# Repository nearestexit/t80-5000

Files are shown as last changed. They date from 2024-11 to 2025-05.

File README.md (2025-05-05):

# T80-5000 & T80-5700

[QMK](https://github.com/qmk/qmk_firmware) Compatible Open Hardware USB-C PCBs for the vintage [Cherry G80-5000](https://web.archive.org/web/20250114051116/https://deskthority.net/wiki/Cherry_G80-5000) split ergonomic keyboard and its companion numpad, the G80-5700.

## Overview
The original G80-5000 has two halves which are attached together with a spring, similar to the IBM M15 and the Apple Adjustable Keyboard. They cannot be detached from each other, and the right half must always act as the host.
The original G80-5700 companion numpad can only function when plugged in to the right half of the G80-5000.

This project brings the G80-5000 & 5700 into the 21st century, with all three pieces able to function independently.
There are four PCBs included in this project: the T80-5000 Left, T80-5000 Right, T80-5000 Daughterboard, and T80-5700.
The T80-5000 Left & Right work with QMK's [split keyboard](https://docs.qmk.fm/features/split_keyboard) functionality, and the T80-5700 functions as an independent keyboard which can be passed through the right half's USB hub.

Production files are included for production at [JLCPCB](https://jlcpcb.com/).

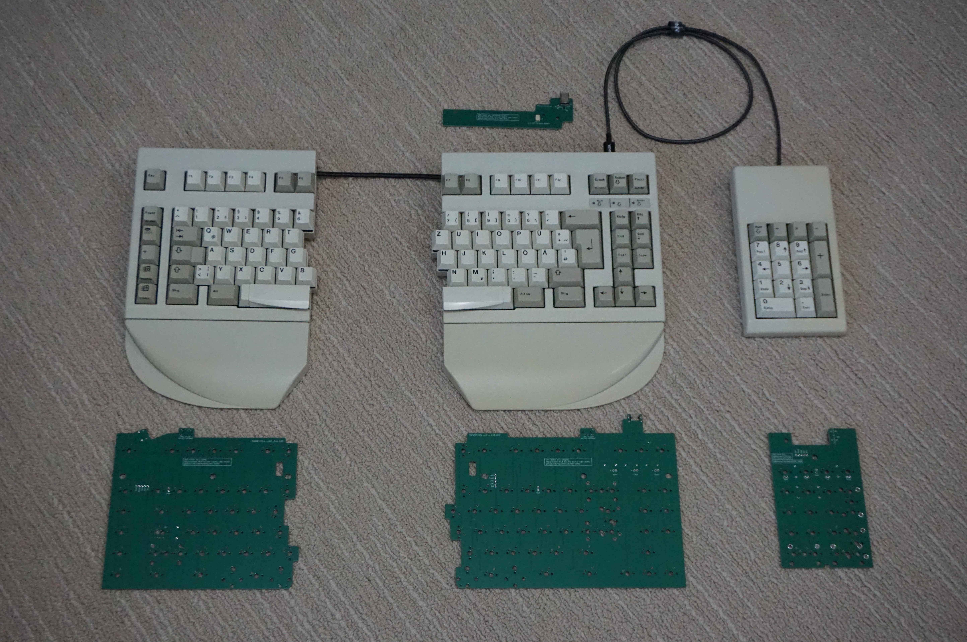
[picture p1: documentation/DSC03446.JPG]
Overview


## Features
 - USB-C in several configuration options, including internally attached and externally detachable
 - Integrated USB2.0 hub intended for T80-5700 numpad to support passthrough like the original G80-5700
 - [RP2040](https://www.raspberrypi.com/products/rp2040/specifications/) MCU(s) supported by the open-source QMK firmware project

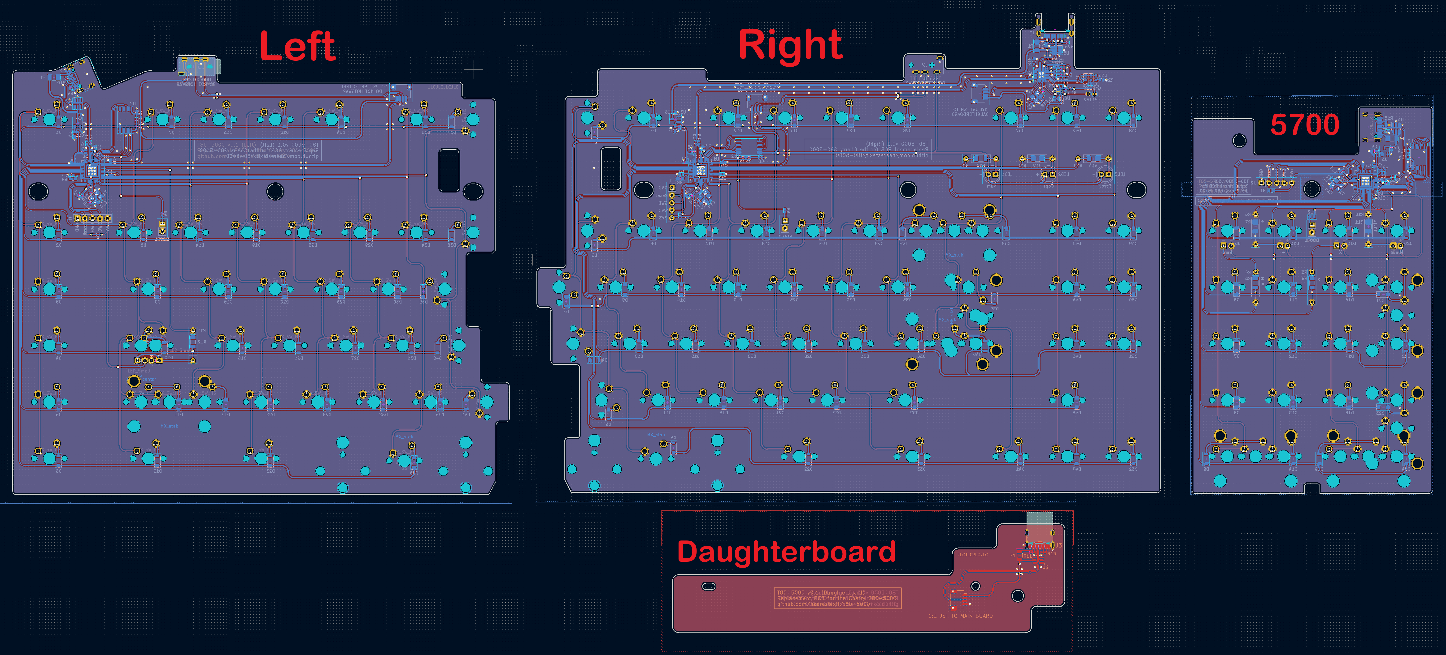
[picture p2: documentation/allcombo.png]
PCB


## Supported layouts
 - ISO and ANSI
 - Split backspace
 - 5x4 ortholinear numpad
 - Stepped and centered caps lock
   
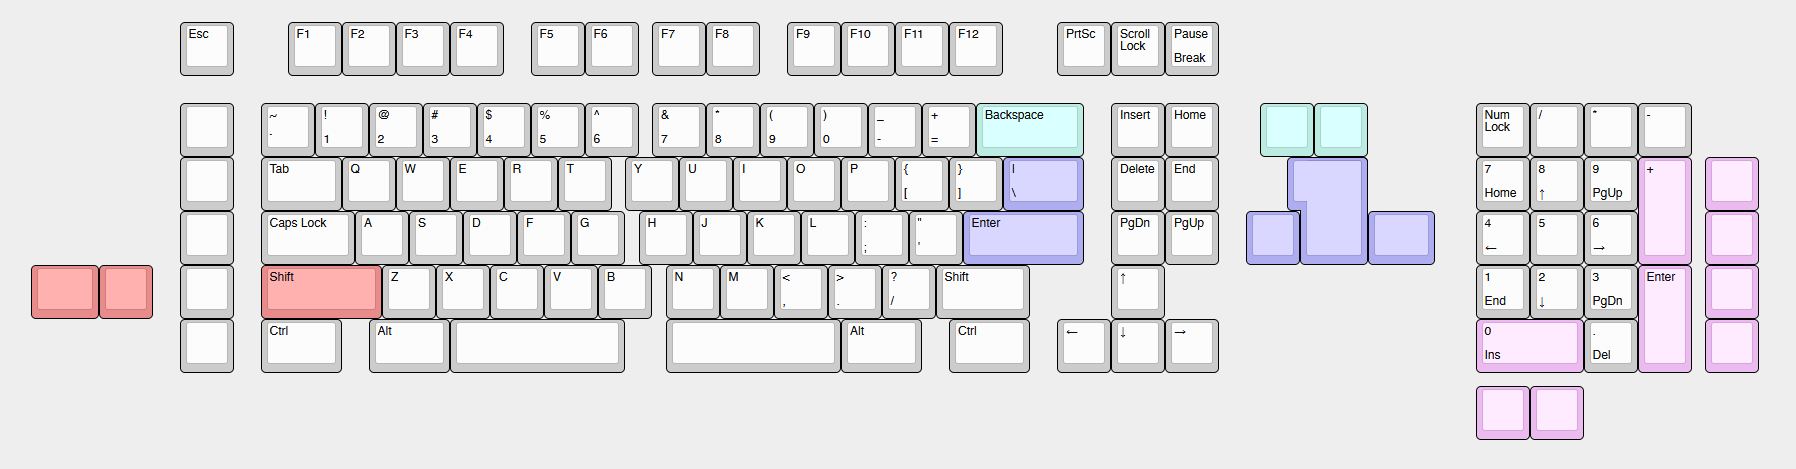
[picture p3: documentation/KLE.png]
T80-5000 and 5700 layout options


## Configuration options
 - The left and right halves can function independently or in a primary/secondary configuration.
 - The left half's USB-C connector is only accessible internally.
 - The right half's USB-C connector takes advantage of the cutout for the original 5-pin mini DIN to be externally detachable. It is recommended to use the right half as the host.
 - The left and right half can be connected by an internally attached TRRS cable or 4-pin JST-SH cable.
 - The JST-SH cable is small enough to fit through a replacement spring.
 - The daughterboard fits in the right half, leverages the same cutout in the case, and serves as the downstream facing USB-C port for the integrated USB hub. It is connected to the right half with a 4-pin JST-SH cable.
 - The T80-5700 has an internally detachable USB-C connector and functions as an independent USB device.

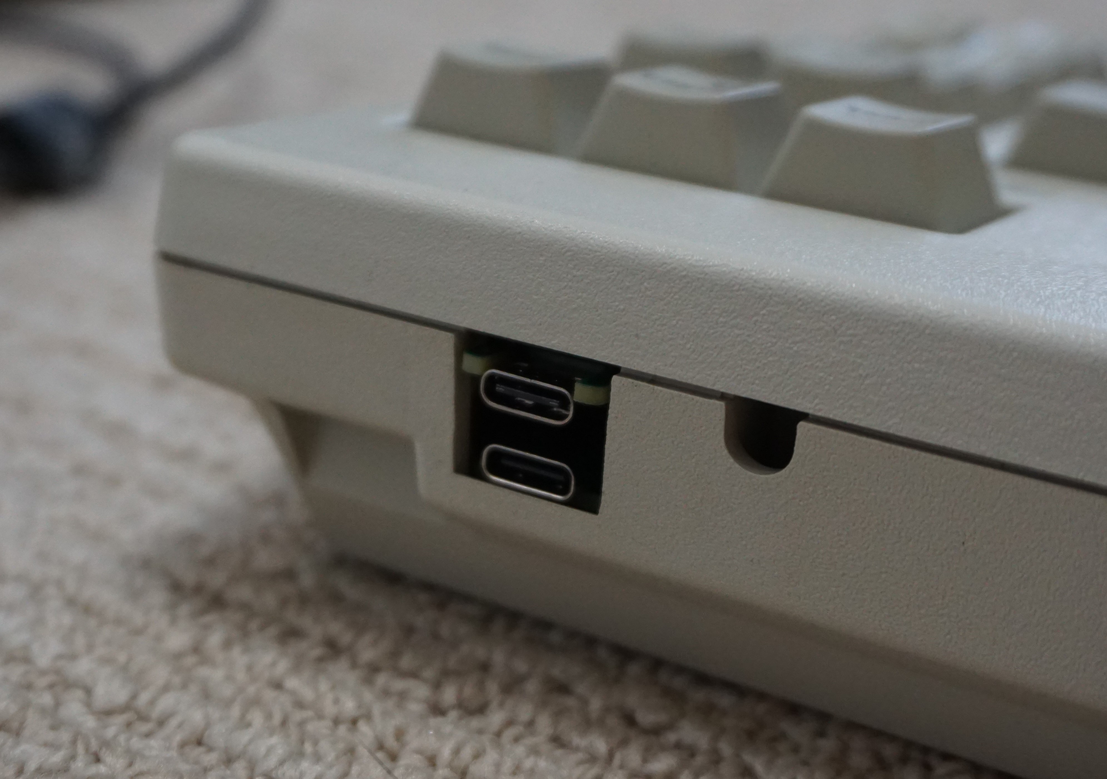
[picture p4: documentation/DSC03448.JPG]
USB port pictures

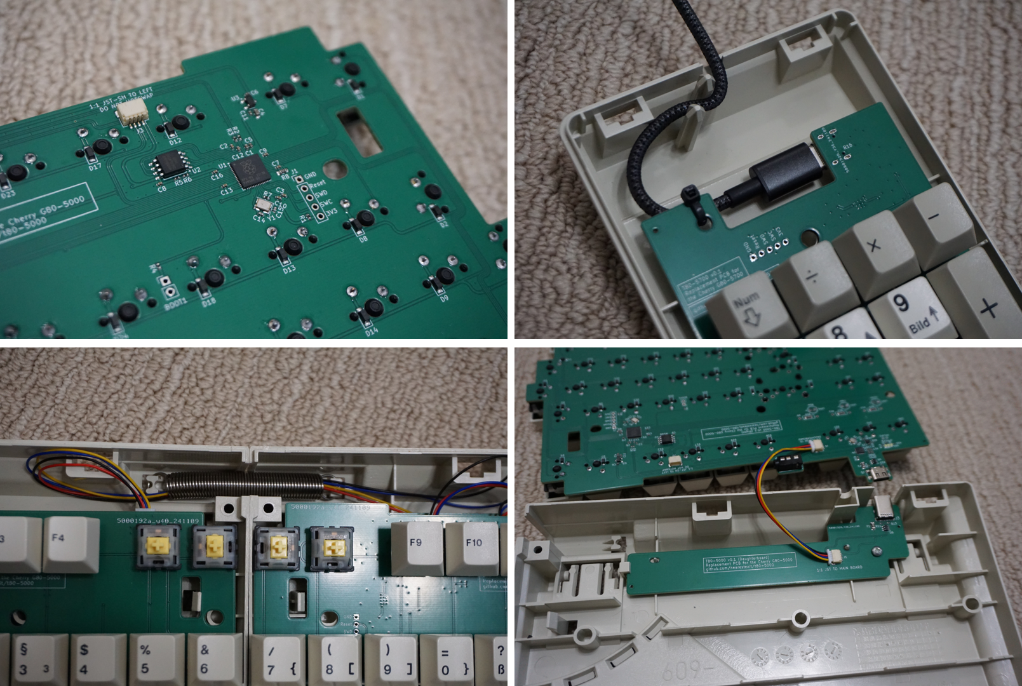
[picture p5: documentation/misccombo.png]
Combo picture


## JLCPCB Ordering Information
1. On jlcpcb.com, click "order now" and "add gerber file"
2. Navigate to the directory with the gerber.zip - for example, t80-5000-left\jlcpcb\production_files
3. Wait for the gerber to upload.
4. Select the number of PCBs you wish to build.
5. Make sure PCB thickness is set to 1.6mm.
6. Make sure Via covering is set to "tented".
7. Make sure Min via hole size/diameter is set to "0.3mm"
8. For "Mark on PCB" select "Order Number (Specify Position)"
9. Turn the "PCB Assembly" option on
10. Make sure PCBA type is set to "Economic"
11. For "Assembly side", if you are ordering the daughterboard select "top side", otherwise select "bottom side"
12. Click "next", and then "next" again
13. Click "Add BOM File" and select the BOM csv - for example, BOM-T80-5000-left.csv
14. Click "Add CPL File" and select the CPL csv - for example, CPL-T80-5000-left.csv
15. Click "Process BOM and CPL"
16. Make sure all parts are in stock - if any are not in stock, you will need to find replacements
17. If you wish to purchase and solder the TRRS sockets separately (recommended to save money), unselect "J2" in this list
18. **IMPORTANT:** Click "Bottom" to view the bottom side of the PCB, and begin inspecting the component placements. You **WILL** need to correct some component rotations. If you are not sure at this step, do not continue!
19. Click "next" and finish checking out.

When I ordered the V0.1 prototype on 11/8/2024, The total price was $207.63 total for Qty. 5 of all PCBs (left, right, daughterboard, and 5700) plus shipping, or roughly $52.71 per set of Left, Right, Daughterboard, and 5700.

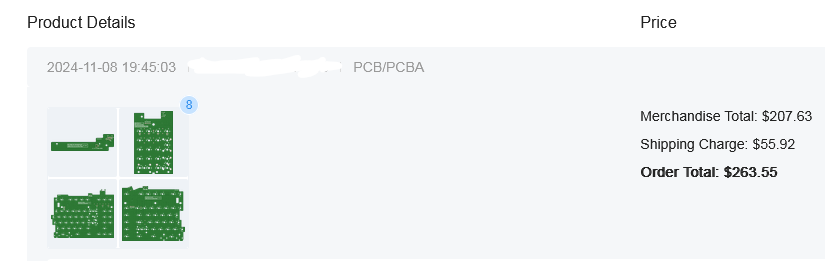
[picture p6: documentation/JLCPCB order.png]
JLCPCB order


## Additional Components:
- 1x 1:1 ~50mm 4-pin JST-SH cable to connect Left PCB to daughterboard
  - **IMPORTANT:** this must be a 1:1 cable, or else you will short VCC to ground!
  - This means that pin 1 of one connector must be wired to pin 1 of the other connector. If you are unsure, lay the cable flat with no wires crossing - if the connectors on either side are the same way up, it is NOT a 1:1 cable. If they are flipped, it is a 1:1 cable.
  - You can get 1:1 JST-SH cables from many places, but I recommend purchasing a Sparkfun QWIIC starter kit like [this](https://www.amazon.com/dp/B08HQ1VSVL)
- 1x 1:1 ~300mm 4-pin JST-SH cable **OR** TRRS cable to connect Left PCB to Right PCB
  - **IMPORTANT:** do not hotswap these connectors! Plugging or unplugging the TRRS connector with power on will short VCC to ground and potentially damage the MCU.
- 3x LEDs for lock lights
  - The board comes with 300 ohm 1206 package resistors pre-soldered. There are holes to add through-hole resistors if you want to change the resistance.
- ~113 MX-compatible switches (this will vary depending on the layout you choose - my ISO configuration uses 108 switches)
- [PJ-320A](https://www.lcsc.com/product-detail/Audio-Connectors_XKB-Connectivity-PJ-320A_C2884926.html) 3.5mm 4 pin TRRS receptacle (optional) - if you wish to use a TRRS cable and choose not to have it soldered by JLCPCB
- Spring (optional) - An image displaying the approximate measurements of the original spring is included in the documentation folder. I used [these](https://www.amazon.com/dp/B0BRHF1DBL) springs.

## Firmware
- [Vial-QMK](https://get.vial.today/) .uf2 files are provided in the firmware folder.
- To put the keyboard into bootloader mode to flash the firmware:
1. Unplug the USB cable
2. Short the BOOT pins with a pair of tweezers
3. Plug the USB cable in
4. Stop shorting the BOOT pins.
- The RP2040 will then be loaded onto your computer as a USB storage device. Drag in the .uf2 firmware file, and it will reboot.
- The boot pins can be found on the Left side by removing the 1 key, the Right side by removing the 0 key, and the Numpad by removing the * key.
- Once you have flashed the firmware, you can change the keymap from [vial.rocks](https://vial.rocks)

## Other Important Notes
- The components are soldered on to the bottom of this PCB. If you are not careful when putting the keyboard together, you can knock components off the PCB.
- The USB-C receptacles for the right half and the downstream-facing USB hub are close enough together that if the downstream USB-C port is used, cables with thick ends will not work.
- If you do not use the downstream-facing USB-C port, there is no limit to the size of the USB-C cable.
- The USB-Hub will not function if the left side is used as the host.

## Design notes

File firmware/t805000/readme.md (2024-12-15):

# nearestexit/t805000

nearestexit/t805000

*A short description of the keyboard/project*

* Keyboard Maintainer: [nearestexit](https://github.com/nearestexit)
* Hardware Supported: *The PCBs, controllers supported*
* Hardware Availability: *Links to where you can find this hardware*

Make example for this keyboard (after setting up your build environment):

    make nearestexit/t805000:default

Flashing example for this keyboard:

    make nearestexit/t805000:default:flash

See the [build environment setup](https://docs.qmk.fm/#/getting_started_build_tools) and the [make instructions](https://docs.qmk.fm/#/getting_started_make_guide) for more information. Brand new to QMK? Start with our [Complete Newbs Guide](https://docs.qmk.fm/#/newbs).

## Bootloader

Enter the bootloader in 3 ways:

* **Bootmagic reset**: Hold down the key at (0,0) in the matrix (usually the top left key or Escape) and plug in the keyboard
* **Physical reset button**: Briefly press the button on the back of the PCB - some may have pads you must short instead
* **Keycode in layout**: Press the key mapped to `QK_BOOT` if it is available

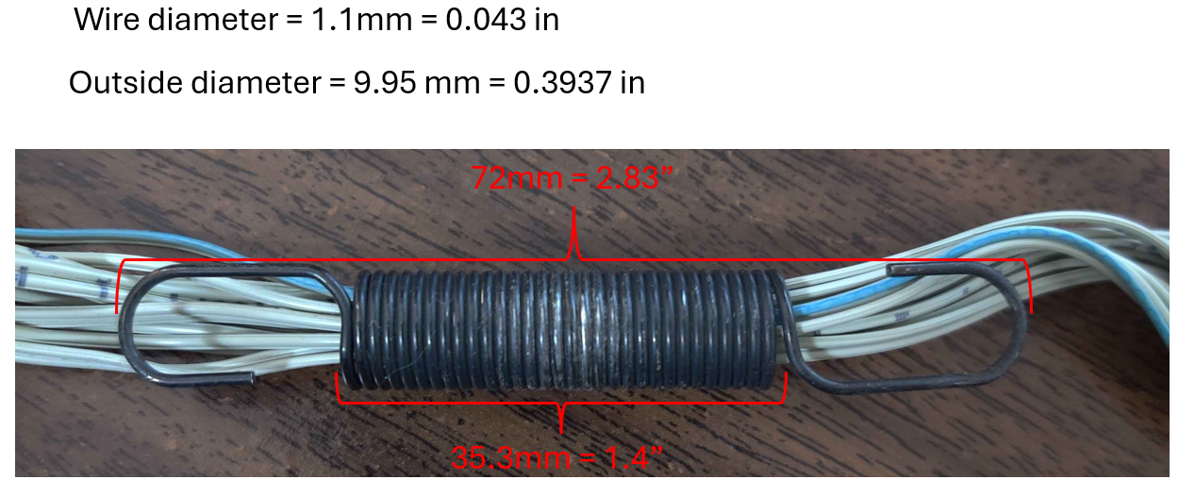
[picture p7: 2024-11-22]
documentation/spring.png

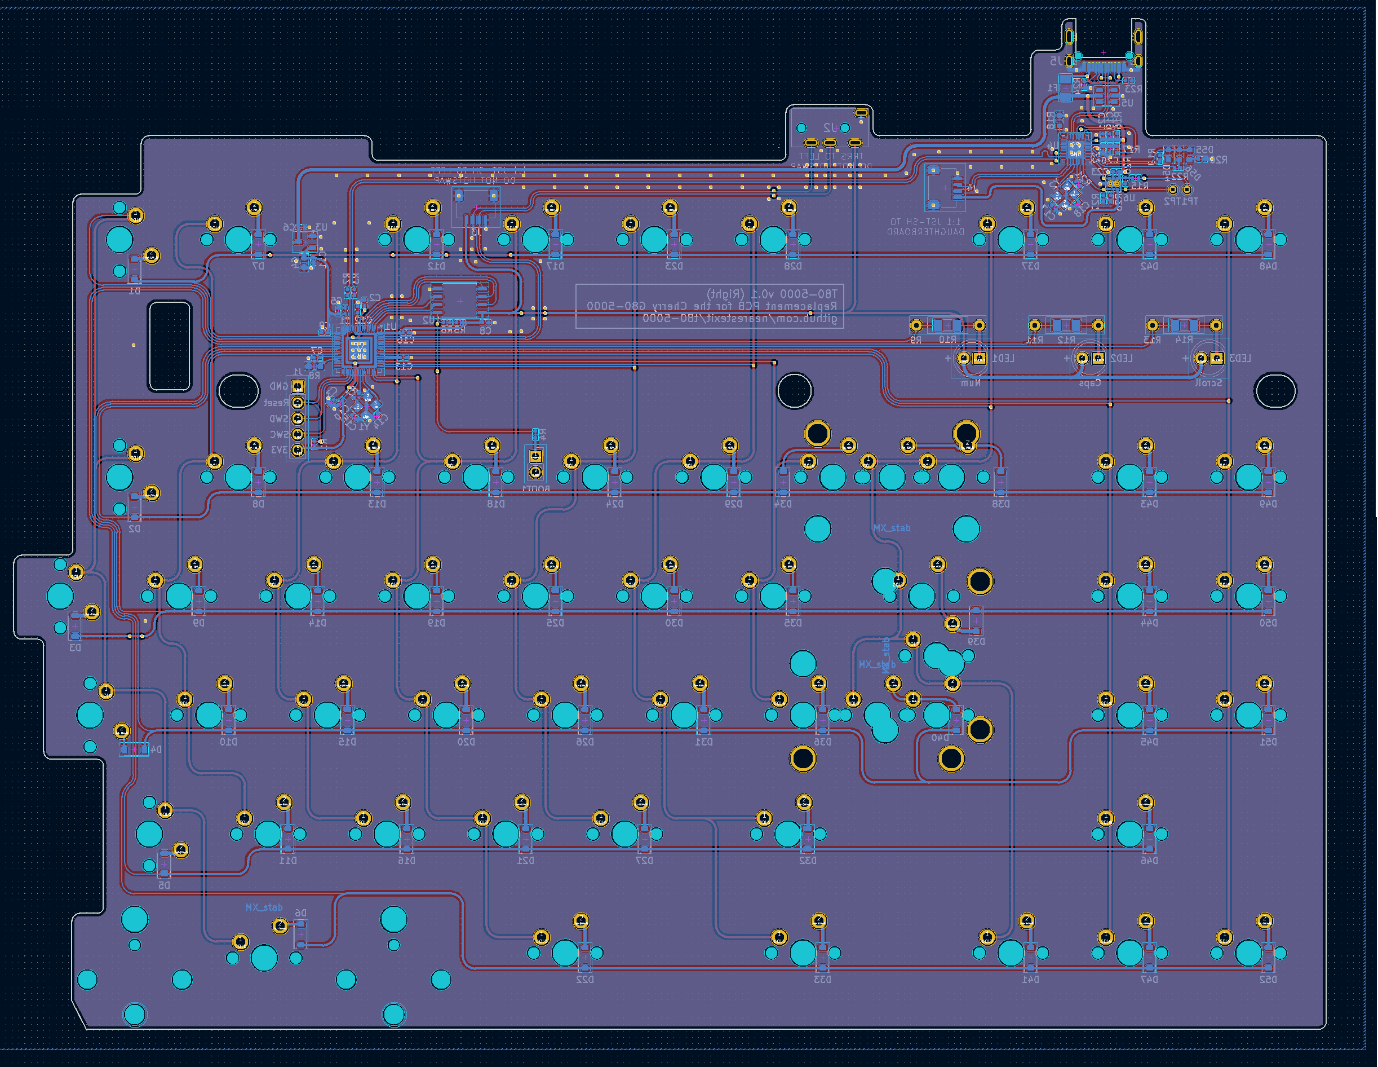
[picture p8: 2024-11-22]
documentation/right.png

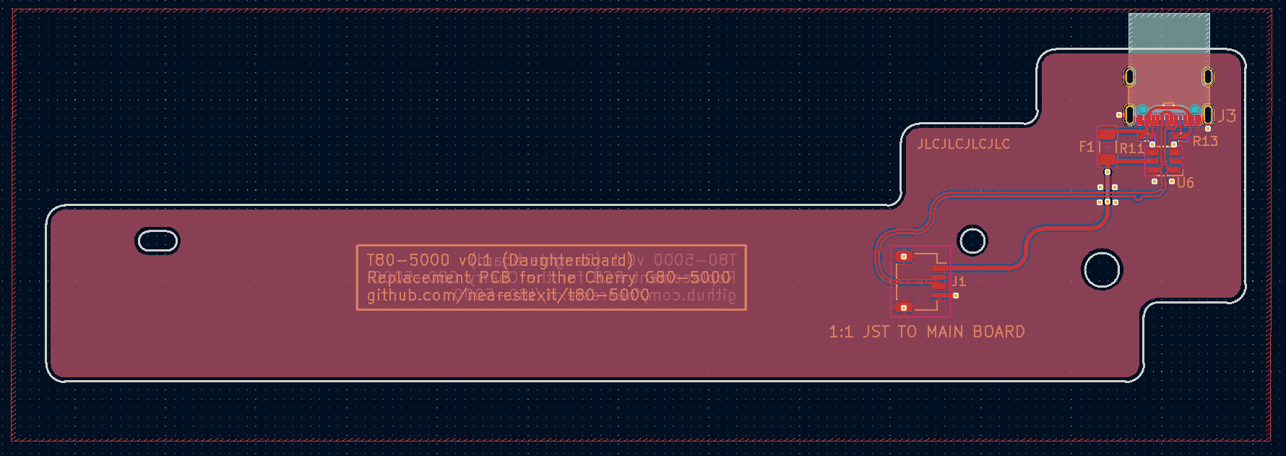
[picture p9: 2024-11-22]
documentation/daughterboard.png

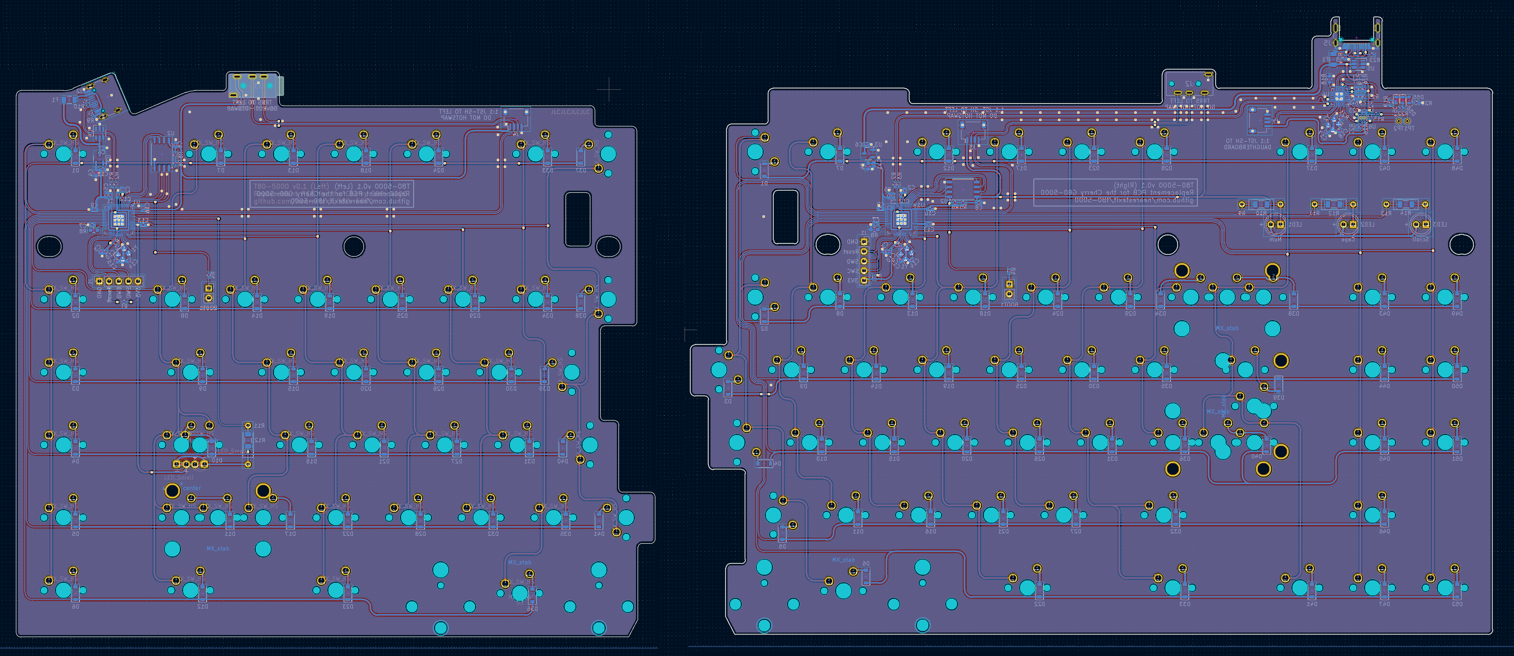
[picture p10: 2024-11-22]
documentation/leftrightcombo.png

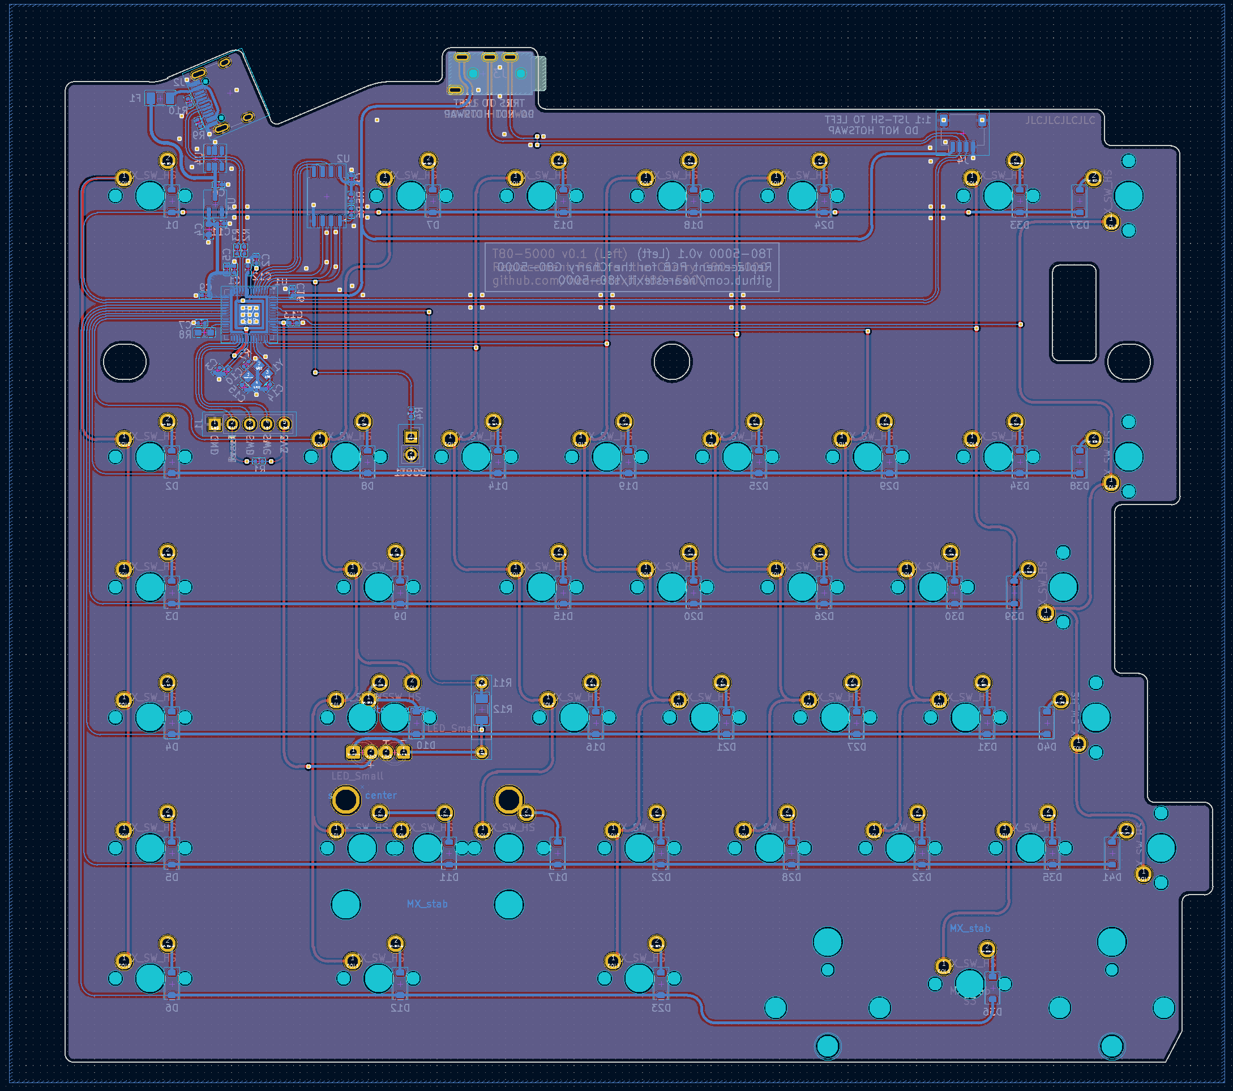
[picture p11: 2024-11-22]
documentation/left.png

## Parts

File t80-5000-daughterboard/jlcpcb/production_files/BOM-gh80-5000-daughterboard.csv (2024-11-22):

Comment | Designator | Footprint | LCSC | Quantity
56k | R11,R13 | R_0402_1005Metric | C114756 | 2
Conn_01x04 | J1 | JST_SH_SM04B-SRSS-TB_1x04-1MP_P1.00mm_Horizontal | C371571 | 1
USB_C_Receptacle_USB2.0_16P | J3 | USB-C-SMD_HANBO_MC-121-L119 | C6332278 | 1
500mA | F1 | Fuse_1206_3216Metric | C70076 | 1
SRV05-4 | U6 | SOT-23-6-routable | C85364 | 1

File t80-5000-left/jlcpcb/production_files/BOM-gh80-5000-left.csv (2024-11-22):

Comment | Designator | Footprint | LCSC | Quantity
1k | R4,R7 | R_0402_1005Metric | C11702 | 2
W25Q128JVS | U2 | SOIC-8_5.23x5.23mm_P1.27mm | C131025 | 1
27R | R2,R3 | R_0402_1005Metric | C138021 | 2
22p | C14,C15 | C_0402_1005Metric | C1555 | 2
USB_C_Receptacle_USB2.0 | J2 | USB_C_Receptacle_HRO_TYPE-C-31-M-12 | C165948 | 1
300 | R12 | R_1206_3216Metric_Pad1.30x1.75mm_HandSolder | C17887 | 1
10u | C4 | C_0603_1608Metric | C19702 | 1
RP2040 | U1 | QFN-56-1EP_7x7mm_P0.4mm_EP3.2x3.2mm | C2040 | 1
5.1k | R8 | R_0603_1608Metric_Pad0.98x0.95mm_HandSolder | C23186 | 1
5.1k | R1,R10,R5,R6,R9 | R_0402_1005Metric | C25905 | 5
AudioJack4 | J3 | AUDIO-TH_XKB_PJ-320A | C2884926 | 1
100n | C10,C12,C13,C16,C2,C3,C7,C8,C9 | C_0402_1005Metric | C307331 | 9
Conn_01x04 | J4 | JST_SH_SM04B-SRSS-TB_1x04-1MP_P1.00mm_Horizontal | C371571 | 1
1u | C1,C11,C5,C6 | C_0402_1005Metric | C52923 | 4
XC6206PxxxMR | U3 | SOT-23-3 | C5446 | 1
500mA | F1 | Fuse_1206_3216Metric | C70076 | 1
D_Small | D1,D10,D11,D12,D13,D14,D15,D16,D17,D18,D19,D2,D20,D21,D22,D23,D24,D25,D26,D27,D28,D29,D3,D30,D31,D32,D33,D34,D35,D36,D37,D38,D39,D4,D40,D41,D5,D6,D7,D8,D9 | D_SOD-123-ShiftedSoldermask | C81598 | 41
SRV05-4 | U4 | SOT-23-6-routable | C85364 | 1
Crystal_GND24 | Y1 | Crystal_SMD_3225-4Pin_3.2x2.5mm | C9002 | 1

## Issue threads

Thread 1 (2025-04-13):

Questions about Ordering Information #18

KohiMiho, 2025-04-13:
Hello friend.
Thanks for bringing a G80-5000 compatible PCB.
Just have a question about the part 'Inspecting component rotations'
I know almost nothing about PCB, so just wonder which things I should inspect before ordering these PCBs.
If you can help about what I should check, it will be very helpful.
Thanks!

nearestexit, 2025-04-29:
Sorry, I don't get notifications so I didn't see this until now. Do you still need help?

KohiMiho, 2025-05-04:
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

Hello friend.
Thanks for the reply.
Yes, it will be best if you can check if all the components are in good direction.
From top to bottom : Daughterboard(Front) / Left(Back) / Right(Back)
I checked the images but seems like all components are at right position, but was concerned if there is a problem cause I do not have knowledge about PCBs

Also, just to add one question, does this PCB supports ordinary cherry clip-in stabilizers for spacebars?
It seems like it supports according to the holes, but was not sure about it.

Thanks for reading friend.
If you can check and reply, that will be very happy.

KohiMiho, 2025-05-15:
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

Thanks to nearestexit, I was able to order it properly working.
Here are the components he told me to rotate before ordering. (Circled in the pics)

Closed 2025-05-15.

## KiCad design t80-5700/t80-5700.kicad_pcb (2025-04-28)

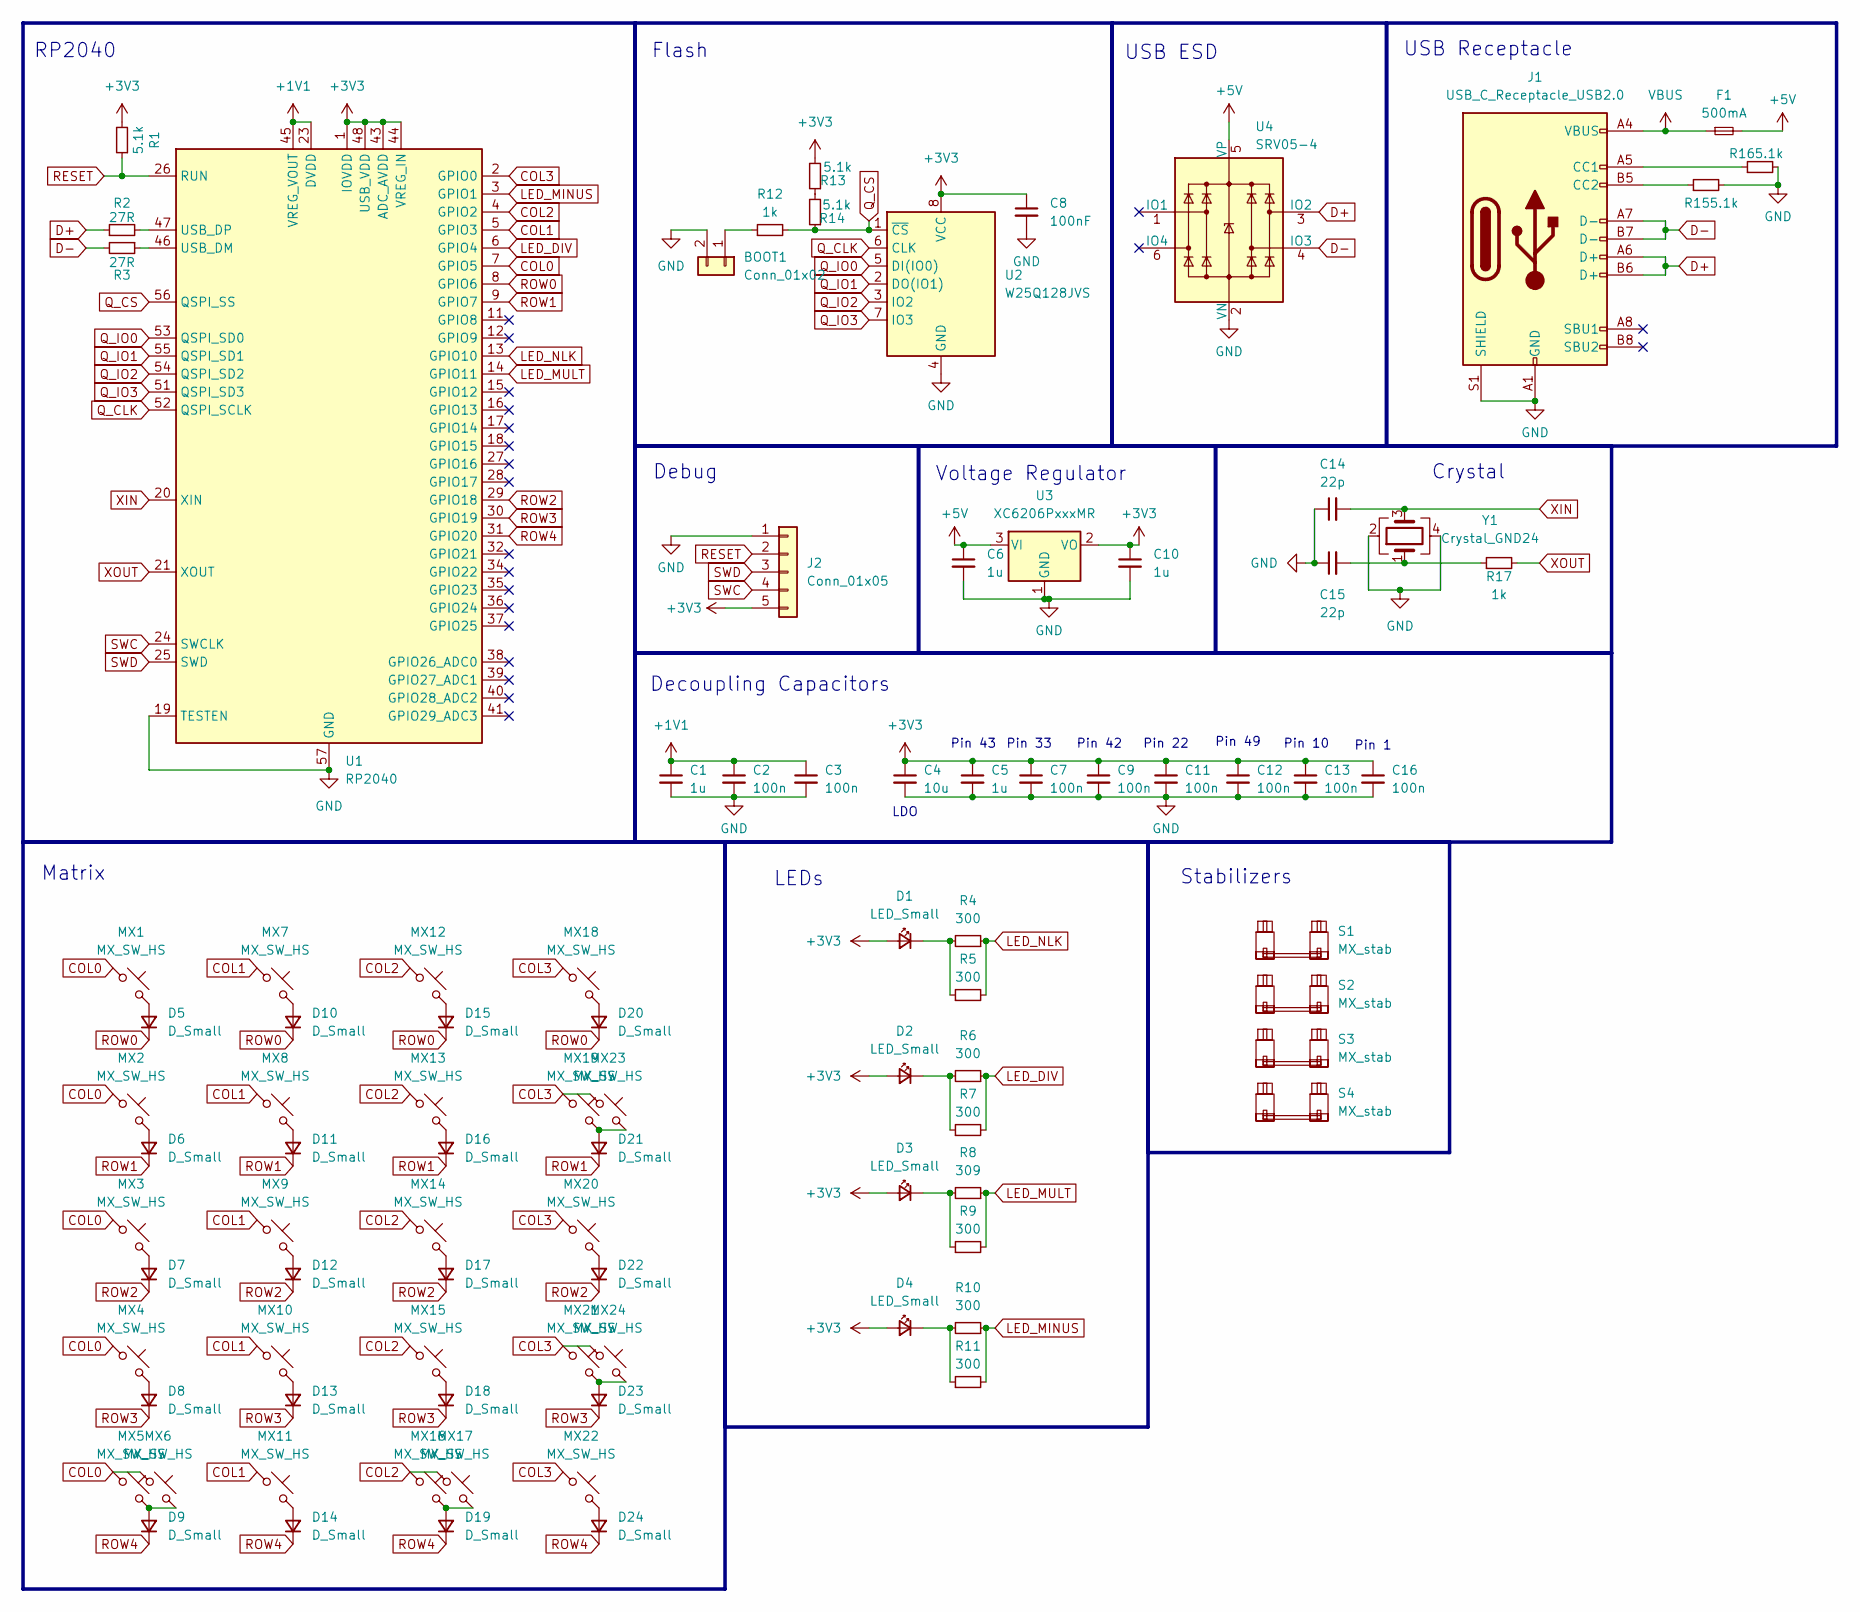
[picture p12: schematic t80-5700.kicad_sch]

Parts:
BOOT1: Conn_01x02; PinHeader_1x02_P2.54mm_Vertical
C1, C5, C6, C10: 1u; C_0402_1005Metric
C2, C3, C7, C9, C11, C12, C13, C16: 100n; C_0402_1005Metric
C4: 10u; C_0603_1608Metric
C8: 100nF; C_0402_1005Metric
C14, C15: 22p; C_0402_1005Metric
D1, D2, D3, D4: LED_Small; LED_MX_3mm
D5, D6, D7, D8, D9, D10, D11, D12, D13, D14, D15, D16, D17, D18, D19, D20, D21, D22, D23, D24: D_Small; D_SOD-123-ShiftedSoldermask
F1: 500mA; Fuse_1206_3216Metric
J1: USB_C_Receptacle_USB2.0; USB_C_Receptacle_HRO_TYPE-C-31-M-12
J2: Conn_01x05; PinHeader_1x05_P2.54mm_Vertical
MX1, MX2, MX3, MX4, MX5, MX6, MX7, MX8, MX9, MX10, MX11, MX12, MX13, MX14, MX15, MX16, MX17, MX18, MX19, MX20, MX21, MX22, MX23, MX24: MX_SW_HS; SW_MX_1u
R1: 5.1k; R_0603_1608Metric
R2, R3: 27R; R_0402_1005Metric
R4, R6, R10: 300; R_Axial_DIN0207_L6.3mm_D2.5mm_P10.16mm_Horizontal
R5, R7, R9, R11: 300; R_1206_3216Metric_Pad1.30x1.75mm_HandSolder
R8: 309; R_Axial_DIN0207_L6.3mm_D2.5mm_P10.16mm_Horizontal
R12: 1k; R_0603_1608Metric
R13, R14, R15, R16: 5.1k; R_0402_1005Metric
R17: 1k; R_0402_1005Metric
S1, S2, S3, S4: MX_stab; STAB_MX_P_2u
U1: RP2040; QFN-56-1EP_7x7mm_P0.4mm_EP3.2x3.2mm
U2: W25Q128JVS; SOIC-8_5.23x5.23mm_P1.27mm
U3: XC6206PxxxMR; SOT-23-3
U4: SRV05-4; SOT-23-6-routable
Y1: Crystal_GND24; Crystal_SMD_3225-4Pin_3.2x2.5mm

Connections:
+1V1: C1.1, C2.1, C3.1, U1.23 (DVDD), U1.45 (VREG_VOUT), U1.50 (DVDD)
+3V3: C4.1, C5.1, C7.1, C8.1, C9.1, C10.1, C11.1, C12.1, C13.1, C16.1, D1.2 (A), D2.2 (A), D3.2 (A), D4.2 (A), J2.5, R1.2, R13.2, U1.1 (IOVDD), U1.10 (IOVDD), U1.22 (IOVDD), U1.33 (IOVDD), U1.42 (IOVDD), U1.43 (ADC_AVDD), U1.44 (VREG_IN), U1.48 (USB_VDD), U1.49 (IOVDD), U2.8 (VCC), U3.2 (VO)
+5V: C6.1, F1.2, U3.3 (VI), U4.5 (VP)
COL0: MX1.1, MX2.1, MX3.1, MX4.1, MX5.1, MX6.1, U1.7 (GPIO5)
COL1: MX7.1, MX8.1, MX9.1, MX10.1, MX11.1, U1.5 (GPIO3)
COL2: MX12.1, MX13.1, MX14.1, MX15.1, MX16.1, MX17.1, U1.4 (GPIO2)
COL3: MX18.1, MX19.1, MX20.1, MX21.1, MX22.1, MX23.1, MX24.1, U1.2 (GPIO0)
D+: J1.A6 (D+), J1.B6 (D+), R2.1, U4.3 (IO2)
D-: J1.A7 (D-), J1.B7 (D-), R3.2, U4.4 (IO3)
GND: BOOT1.2, C1.2, C2.2, C3.2, C4.2, C5.2, C6.2, C7.2, C8.2, C9.2, C10.2, C11.2, C12.2, C13.2, C14.1, C15.1, C16.2, J1.A1 (GND), J1.A12 (GND), J1.B1 (GND), J1.B12 (GND), J1.S1 (SHIELD), J2.1, R15.2, R16.2, U1.19 (TESTEN), U1.57 (GND), U2.4 (GND), U3.1 (GND), U4.2 (VN), Y1.2, Y1.4
LED_DIV: R6.1, R7.2, U1.6 (GPIO4)
LED_MINUS: R10.1, R11.2, U1.3 (GPIO1)
LED_MULT: R8.1, R9.2, U1.14 (GPIO11)
LED_NLK: R4.1, R5.2, U1.13 (GPIO10)
unnamed: BOOT1.1, R12.1
unnamed: C15.2, R17.1, Y1.1
unnamed: D1.1 (K), R4.2, R5.1
unnamed: D2.1 (K), R6.2, R7.1
unnamed: D3.1 (K), R8.2, R9.1
unnamed: D4.1 (K), R10.2, R11.1
unnamed: D5.2 (A), MX1.2
unnamed: D6.2 (A), MX2.2
unnamed: D7.2 (A), MX3.2
unnamed: D8.2 (A), MX4.2
unnamed: D9.2 (A), MX5.2, MX6.2
unnamed: D10.2 (A), MX7.2
unnamed: D11.2 (A), MX8.2
unnamed: D12.2 (A), MX9.2
unnamed: D13.2 (A), MX10.2
unnamed: D14.2 (A), MX11.2
unnamed: D15.2 (A), MX12.2
unnamed: D16.2 (A), MX13.2
unnamed: D17.2 (A), MX14.2
unnamed: D18.2 (A), MX15.2
unnamed: D19.2 (A), MX16.2, MX17.2
unnamed: D20.2 (A), MX18.2
unnamed: D21.2 (A), MX19.2, MX23.2
unnamed: D22.2 (A), MX20.2
unnamed: D23.2 (A), MX21.2, MX24.2
unnamed: D24.2 (A), MX22.2
unnamed: J1.A5 (CC1), R16.1
unnamed: J1.B5 (CC2), R15.1
unnamed: R13.1, R14.2
unnamed: R3.1, U1.46 (USB_DM)
unnamed: R2.2, U1.47 (USB_DP)
Q_CLK: U1.52 (QSPI_SCLK), U2.6 (CLK)
Q_CS: R12.2, R14.1, U1.56 (QSPI_SS), U2.1 (~CS)
Q_IO0: U1.53 (QSPI_SD0), U2.5 (DI(IO0))
Q_IO1: U1.55 (QSPI_SD1), U2.2 (DO(IO1))
Q_IO2: U1.54 (QSPI_SD2), U2.3 (IO2)
Q_IO3: U1.51 (QSPI_SD3), U2.7 (IO3)
RESET: J2.2, R1.1, U1.26 (RUN)
ROW0: D5.1 (K), D10.1 (K), D15.1 (K), D20.1 (K), U1.8 (GPIO6)
ROW1: D6.1 (K), D11.1 (K), D16.1 (K), D21.1 (K), U1.9 (GPIO7)
ROW2: D7.1 (K), D12.1 (K), D17.1 (K), D22.1 (K), U1.29 (GPIO18)
ROW3: D8.1 (K), D13.1 (K), D18.1 (K), D23.1 (K), U1.30 (GPIO19)
ROW4: D9.1 (K), D14.1 (K), D19.1 (K), D24.1 (K), U1.31 (GPIO20)
SWC: J2.4, U1.24 (SWCLK)
SWD: J2.3, U1.25 (SWD)
VBUS: F1.1, J1.A4 (VBUS), J1.A9 (VBUS), J1.B4 (VBUS), J1.B9 (VBUS)
XIN: C14.2, U1.20 (XIN), Y1.3
XOUT: R17.2, U1.21 (XOUT)

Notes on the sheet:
Pin 43
LDO
USB ESD
Stabilizers
Crystal
Pin 1
USB Receptacle
Pin 33
Pin 49
Debug
LEDs
Pin 10
Decoupling Capacitors
Flash
Pin 42
RP2040
Voltage Regulator
Matrix
Pin 22

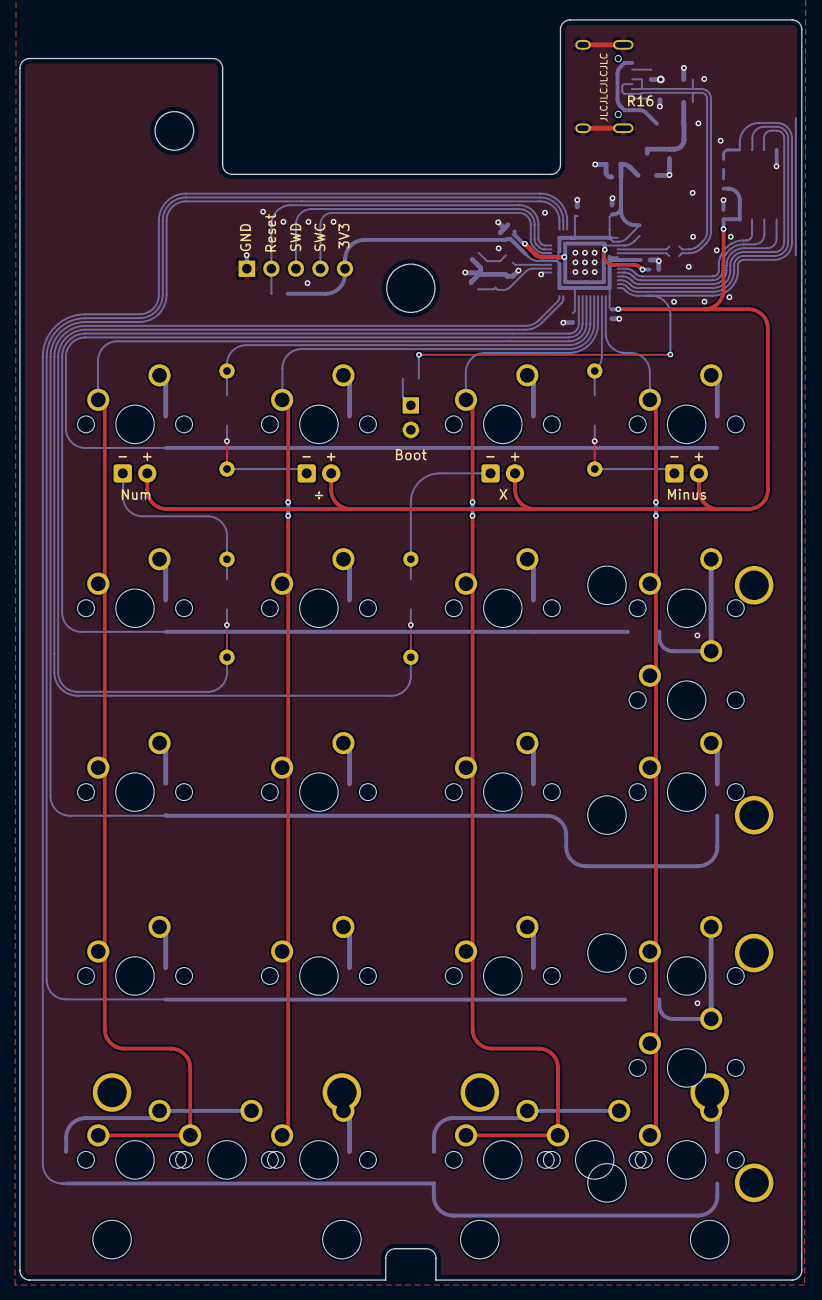
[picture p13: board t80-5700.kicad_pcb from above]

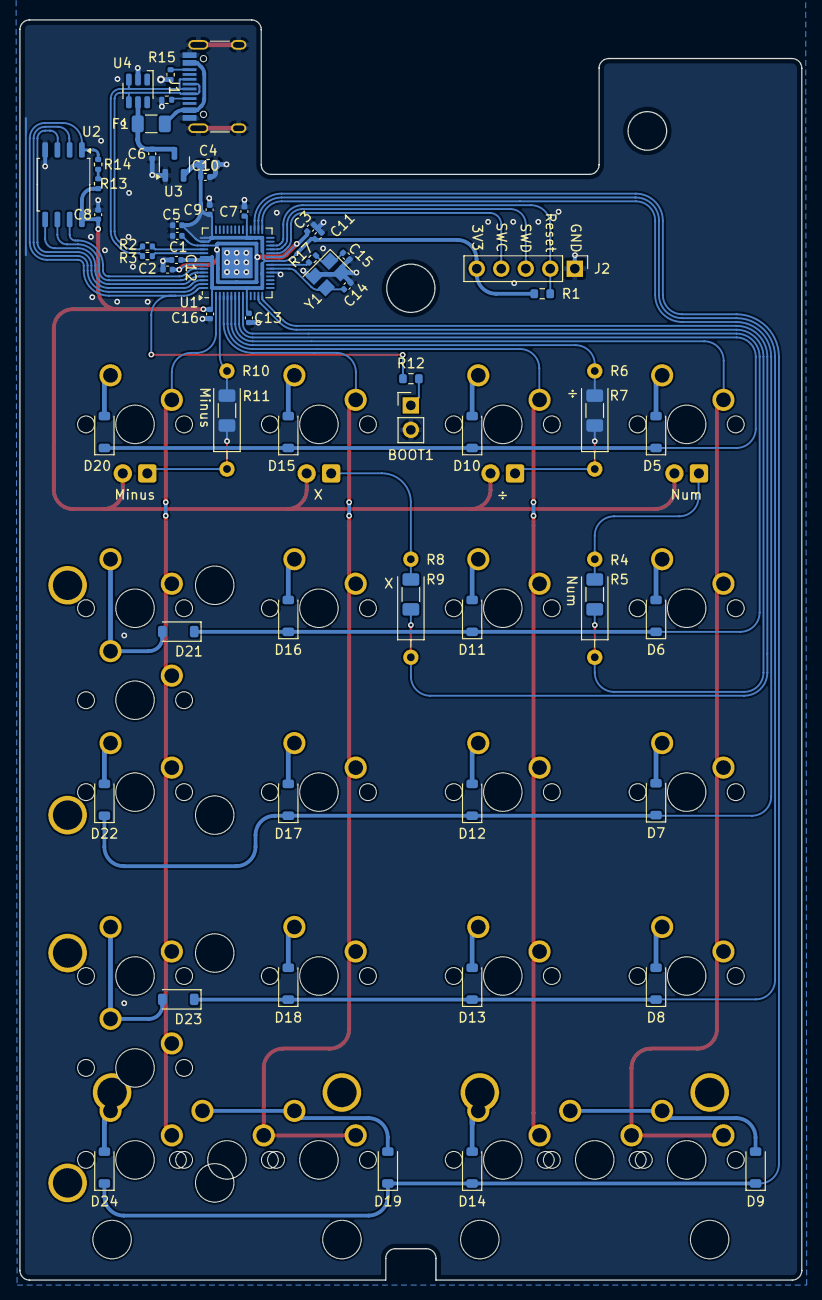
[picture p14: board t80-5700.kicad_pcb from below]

Board: 2 copper layers, 81.0 x 130.6 mm, 94 parts (70 on the bottom side), 61 nets.

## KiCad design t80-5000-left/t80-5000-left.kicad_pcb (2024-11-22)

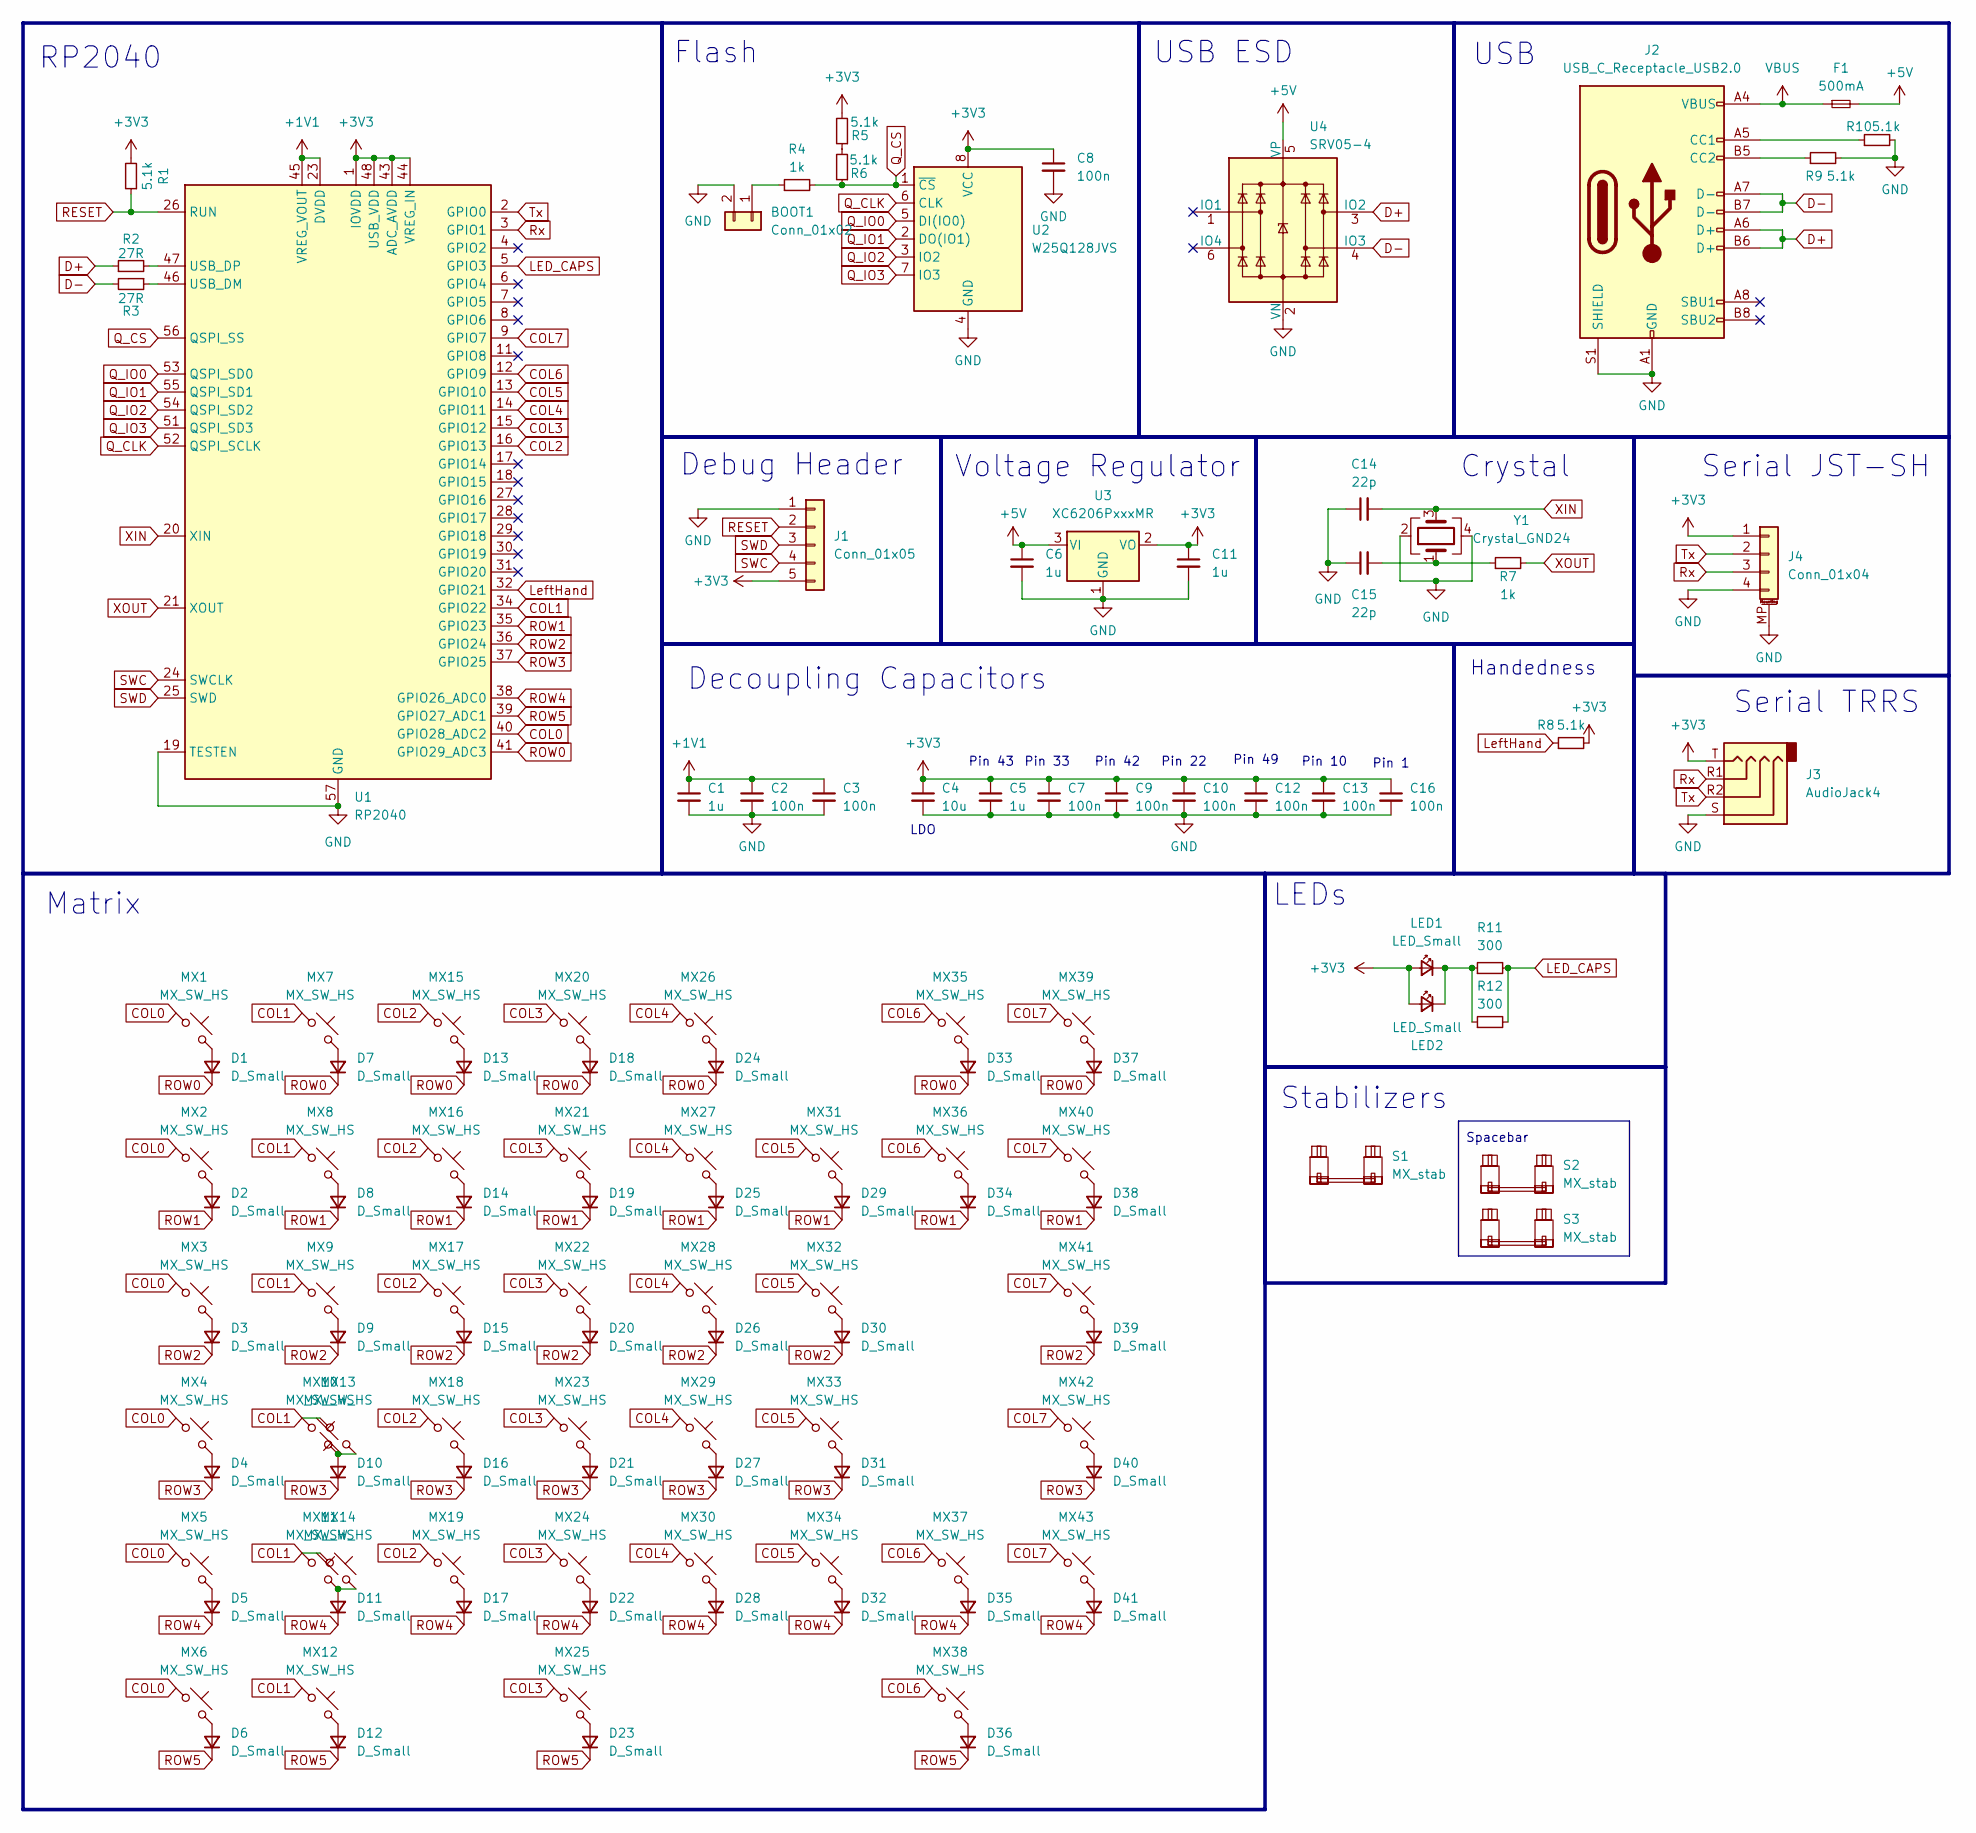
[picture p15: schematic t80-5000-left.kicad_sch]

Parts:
BOOT1: Conn_01x02; PinHeader_1x02_P2.54mm_Vertical
C1, C5, C6, C11: 1u; C_0402_1005Metric
C2, C3, C7, C8, C9, C10, C12, C13, C16: 100n; C_0402_1005Metric
C4: 10u; C_0603_1608Metric
C14, C15: 22p; C_0402_1005Metric
D1, D2, D3, D4, D5, D6, D7, D8, D9, D10, D11, D12, D13, D14, D15, D16, D17, D18, D19, D20, D21, D22, D23, D24, D25, D26, D27, D28, D29, D30, D31, D32, D33, D34, D35, D36, D37, D38, D39, D40, D41: D_Small; D_SOD-123-ShiftedSoldermask
F1: 500mA; Fuse_1206_3216Metric
J1: Conn_01x05; PinHeader_1x05_P2.54mm_Vertical
J2: USB_C_Receptacle_USB2.0; USB_C_Receptacle_HRO_TYPE-C-31-M-12
J3: AudioJack4; AUDIO-TH_XKB_PJ-320A
J4: Conn_01x04; JST_SH_SM04B-SRSS-TB_1x04-1MP_P1.00mm_Horizontal
LED1, LED2: LED_Small; LED_MX_3mm
MX1, MX2, MX3, MX4, MX5, MX6, MX7, MX8, MX9, MX10, MX11, MX12, MX13, MX14, MX15, MX16, MX17, MX18, MX19, MX20, MX21, MX22, MX23, MX24, MX25, MX26, MX27, MX28, MX29, MX30, MX31, MX32, MX33, MX34, MX35, MX36, MX37, MX38, MX39, MX40, MX41, MX42, MX43: MX_SW_HS; SW_MX_1u
R1, R5, R6, R9, R10: 5.1k; R_0402_1005Metric
R2, R3: 27R; R_0402_1005Metric
R4, R7: 1k; R_0402_1005Metric
R8: 5.1k; R_0603_1608Metric_Pad0.98x0.95mm_HandSolder
R11: 300; R_Axial_DIN0207_L6.3mm_D2.5mm_P10.16mm_Horizontal
R12: 300; R_1206_3216Metric_Pad1.30x1.75mm_HandSolder
S1: MX_stab; STAB_MX_P_2u
S2: MX_stab; STAB_MX_3.5u_5000
S3: MX_stab; STAB_MX_5000
U1: RP2040; QFN-56-1EP_7x7mm_P0.4mm_EP3.2x3.2mm
U2: W25Q128JVS; SOIC-8_5.23x5.23mm_P1.27mm
U3: XC6206PxxxMR; SOT-23-3
U4: SRV05-4; SOT-23-6-routable
Y1: Crystal_GND24; Crystal_SMD_3225-4Pin_3.2x2.5mm

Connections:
+1V1: C1.1, C2.1, C3.1, U1.23 (DVDD), U1.45 (VREG_VOUT), U1.50 (DVDD)
+3V3: C4.1, C5.1, C7.1, C8.1, C9.1, C10.1, C11.1, C12.1, C13.1, C16.1, J1.5, J3.T, J4.1, LED1.2 (A), LED2.2 (A), R1.2, R5.2, R8.2, U1.1 (IOVDD), U1.10 (IOVDD), U1.22 (IOVDD), U1.33 (IOVDD), U1.42 (IOVDD), U1.43 (ADC_AVDD), U1.44 (VREG_IN), U1.48 (USB_VDD), U1.49 (IOVDD), U2.8 (VCC), U3.2 (VO)
+5V: C6.1, F1.2, U3.3 (VI), U4.5 (VP)
COL0: MX1.1, MX2.1, MX3.1, MX4.1, MX5.1, MX6.1, U1.40 (GPIO28_ADC2)
COL1: MX7.1, MX8.1, MX9.1, MX10.1, MX11.1, MX12.1, MX13.2, MX14.1, U1.34 (GPIO22)
COL2: MX15.1, MX16.1, MX17.1, MX18.1, MX19.1, U1.16 (GPIO13)
COL3: MX20.1, MX21.1, MX22.1, MX23.1, MX24.1, MX25.1, U1.15 (GPIO12)
COL4: MX26.1, MX27.1, MX28.1, MX29.1, MX30.1, U1.14 (GPIO11)
COL5: MX31.1, MX32.1, MX33.1, MX34.1, U1.13 (GPIO10)
COL6: MX35.1, MX36.1, MX37.1, MX38.1, U1.12 (GPIO9)
COL7: MX39.1, MX40.1, MX41.1, MX42.1, MX43.1, U1.9 (GPIO7)
D+: J2.A6 (D+), J2.B6 (D+), R2.1, U4.3 (IO2)
D-: J2.A7 (D-), J2.B7 (D-), R3.2, U4.4 (IO3)
GND: BOOT1.2, C1.2, C2.2, C3.2, C4.2, C5.2, C6.2, C7.2, C8.2, C9.2, C10.2, C11.2, C12.2, C13.2, C14.1, C15.1, C16.2, J1.1, J2.A1 (GND), J2.A12 (GND), J2.B1 (GND), J2.B12 (GND), J2.S1 (SHIELD), J3.S, J4.4, J4.MP (MountPin), R9.2, R10.2, U1.19 (TESTEN), U1.57 (GND), U2.4 (GND), U3.1 (GND), U4.2 (VN), Y1.2, Y1.4
LED_CAPS: R11.2, R12.2, U1.5 (GPIO3)
LeftHand: R8.1, U1.32 (GPIO21)
unnamed: BOOT1.1, R4.1
unnamed: C15.2, R7.1, Y1.1
unnamed: D1.2 (A), MX1.2
unnamed: D2.2 (A), MX2.2
unnamed: D3.2 (A), MX3.2
unnamed: D4.2 (A), MX4.2
unnamed: D5.2 (A), MX5.2
unnamed: D6.2 (A), MX6.2
unnamed: D7.2 (A), MX7.2
unnamed: D8.2 (A), MX8.2
unnamed: D9.2 (A), MX9.2
unnamed: D10.2 (A), MX10.2, MX13.1
unnamed: D11.2 (A), MX11.2, MX14.2
unnamed: D12.2 (A), MX12.2
unnamed: D13.2 (A), MX15.2
unnamed: D14.2 (A), MX16.2
unnamed: D15.2 (A), MX17.2
unnamed: D16.2 (A), MX18.2
unnamed: D17.2 (A), MX19.2
unnamed: D18.2 (A), MX20.2
unnamed: D19.2 (A), MX21.2
unnamed: D20.2 (A), MX22.2
unnamed: D21.2 (A), MX23.2
unnamed: D22.2 (A), MX24.2
unnamed: D23.2 (A), MX25.2
unnamed: D24.2 (A), MX26.2
unnamed: D25.2 (A), MX27.2
unnamed: D26.2 (A), MX28.2
unnamed: D27.2 (A), MX29.2
unnamed: D28.2 (A), MX30.2
unnamed: D29.2 (A), MX31.2
unnamed: D30.2 (A), MX32.2
unnamed: D31.2 (A), MX33.2
unnamed: D32.2 (A), MX34.2
unnamed: D33.2 (A), MX35.2
unnamed: D34.2 (A), MX36.2
unnamed: D35.2 (A), MX37.2
unnamed: D36.2 (A), MX38.2
unnamed: D37.2 (A), MX39.2
unnamed: D38.2 (A), MX40.2
unnamed: D39.2 (A), MX41.2
unnamed: D40.2 (A), MX42.2
unnamed: D41.2 (A), MX43.2
unnamed: J2.A5 (CC1), R10.1
unnamed: J2.B5 (CC2), R9.1
unnamed: LED1.1 (K), LED2.1 (K), R11.1, R12.1
unnamed: R5.1, R6.2
unnamed: R3.1, U1.46 (USB_DM)
unnamed: R2.2, U1.47 (USB_DP)
Q_CLK: U1.52 (QSPI_SCLK), U2.6 (CLK)
Q_CS: R4.2, R6.1, U1.56 (QSPI_SS), U2.1 (~CS)
Q_IO0: U1.53 (QSPI_SD0), U2.5 (DI(IO0))
Q_IO1: U1.55 (QSPI_SD1), U2.2 (DO(IO1))
Q_IO2: U1.54 (QSPI_SD2), U2.3 (IO2)
Q_IO3: U1.51 (QSPI_SD3), U2.7 (IO3)
RESET: J1.2, R1.1, U1.26 (RUN)
ROW0: D1.1 (K), D7.1 (K), D13.1 (K), D18.1 (K), D24.1 (K), D33.1 (K), D37.1 (K), U1.41 (GPIO29_ADC3)
ROW1: D2.1 (K), D8.1 (K), D14.1 (K), D19.1 (K), D25.1 (K), D29.1 (K), D34.1 (K), D38.1 (K), U1.35 (GPIO23)
ROW2: D3.1 (K), D9.1 (K), D15.1 (K), D20.1 (K), D26.1 (K), D30.1 (K), D39.1 (K), U1.36 (GPIO24)
ROW3: D4.1 (K), D10.1 (K), D16.1 (K), D21.1 (K), D27.1 (K), D31.1 (K), D40.1 (K), U1.37 (GPIO25)
ROW4: D5.1 (K), D11.1 (K), D17.1 (K), D22.1 (K), D28.1 (K), D32.1 (K), D35.1 (K), D41.1 (K), U1.38 (GPIO26_ADC0)
ROW5: D6.1 (K), D12.1 (K), D23.1 (K), D36.1 (K), U1.39 (GPIO27_ADC1)
Rx: J3.R1, J4.3, U1.3 (GPIO1)
SWC: J1.4, U1.24 (SWCLK)
SWD: J1.3, U1.25 (SWD)
Tx: J3.R2, J4.2, U1.2 (GPIO0)
VBUS: F1.1, J2.A4 (VBUS), J2.A9 (VBUS), J2.B4 (VBUS), J2.B9 (VBUS)
XIN: C14.2, U1.20 (XIN), Y1.3
XOUT: R7.2, U1.21 (XOUT)

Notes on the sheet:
Decoupling Capacitors
Debug Header
LDO
Stabilizers
Pin 42
RP2040
Pin 10
Handedness
USB
Voltage Regulator
Flash
Serial JST-SH
LEDs
Crystal
USB ESD
Spacebar
Pin 1
Pin 49
Pin 22
Pin 33
Serial TRRS
Matrix
Pin 43

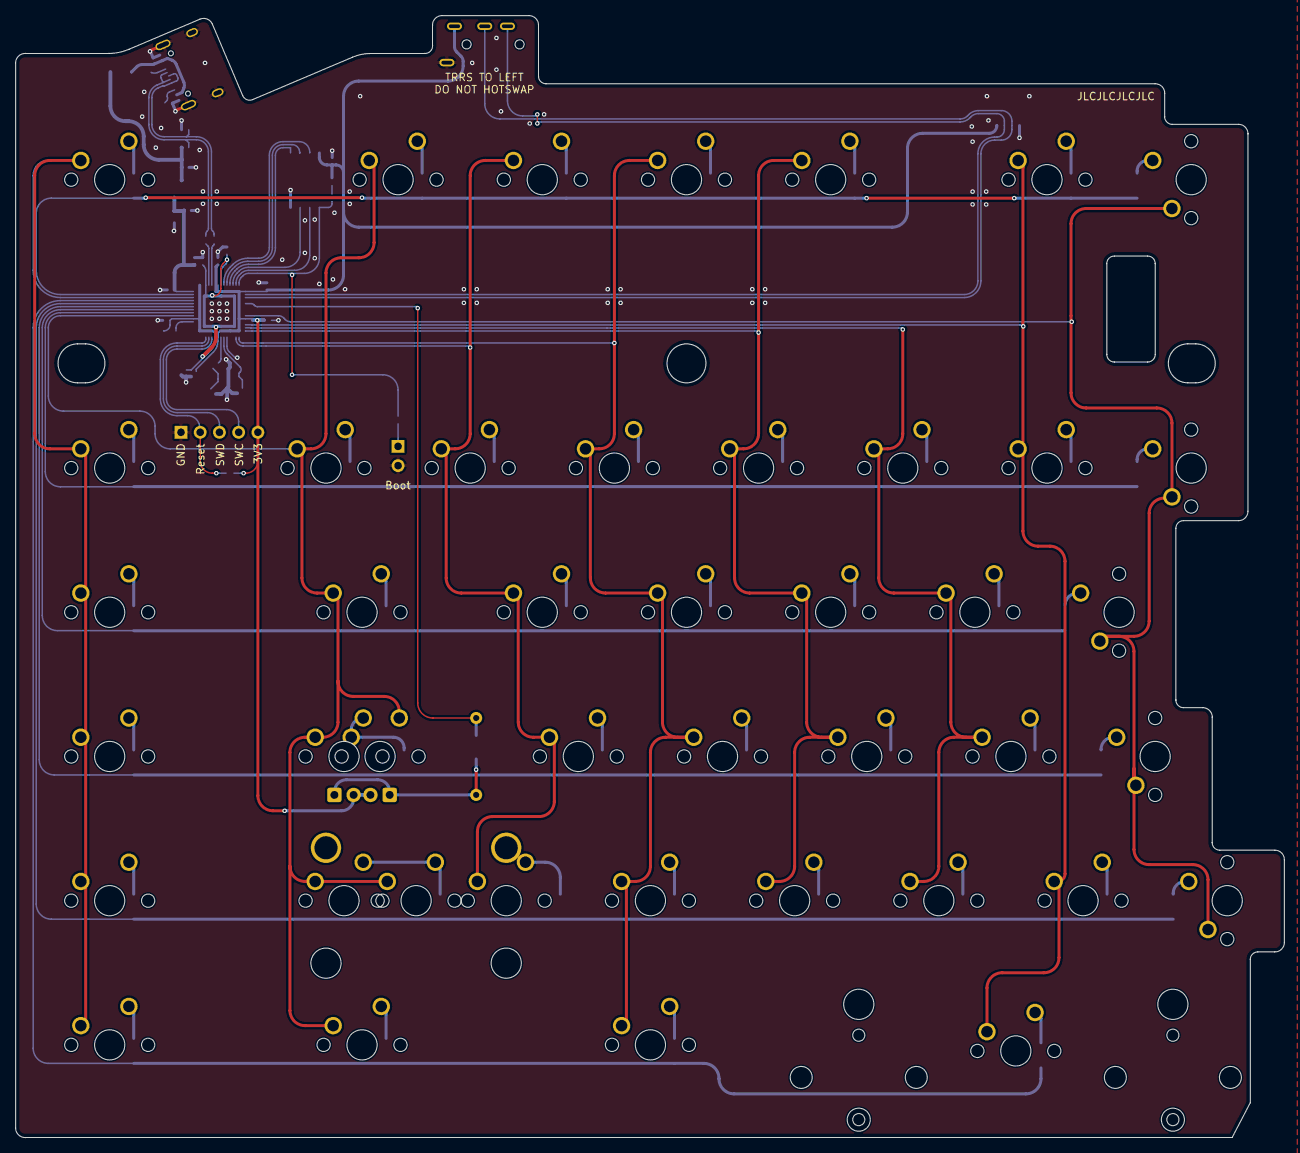
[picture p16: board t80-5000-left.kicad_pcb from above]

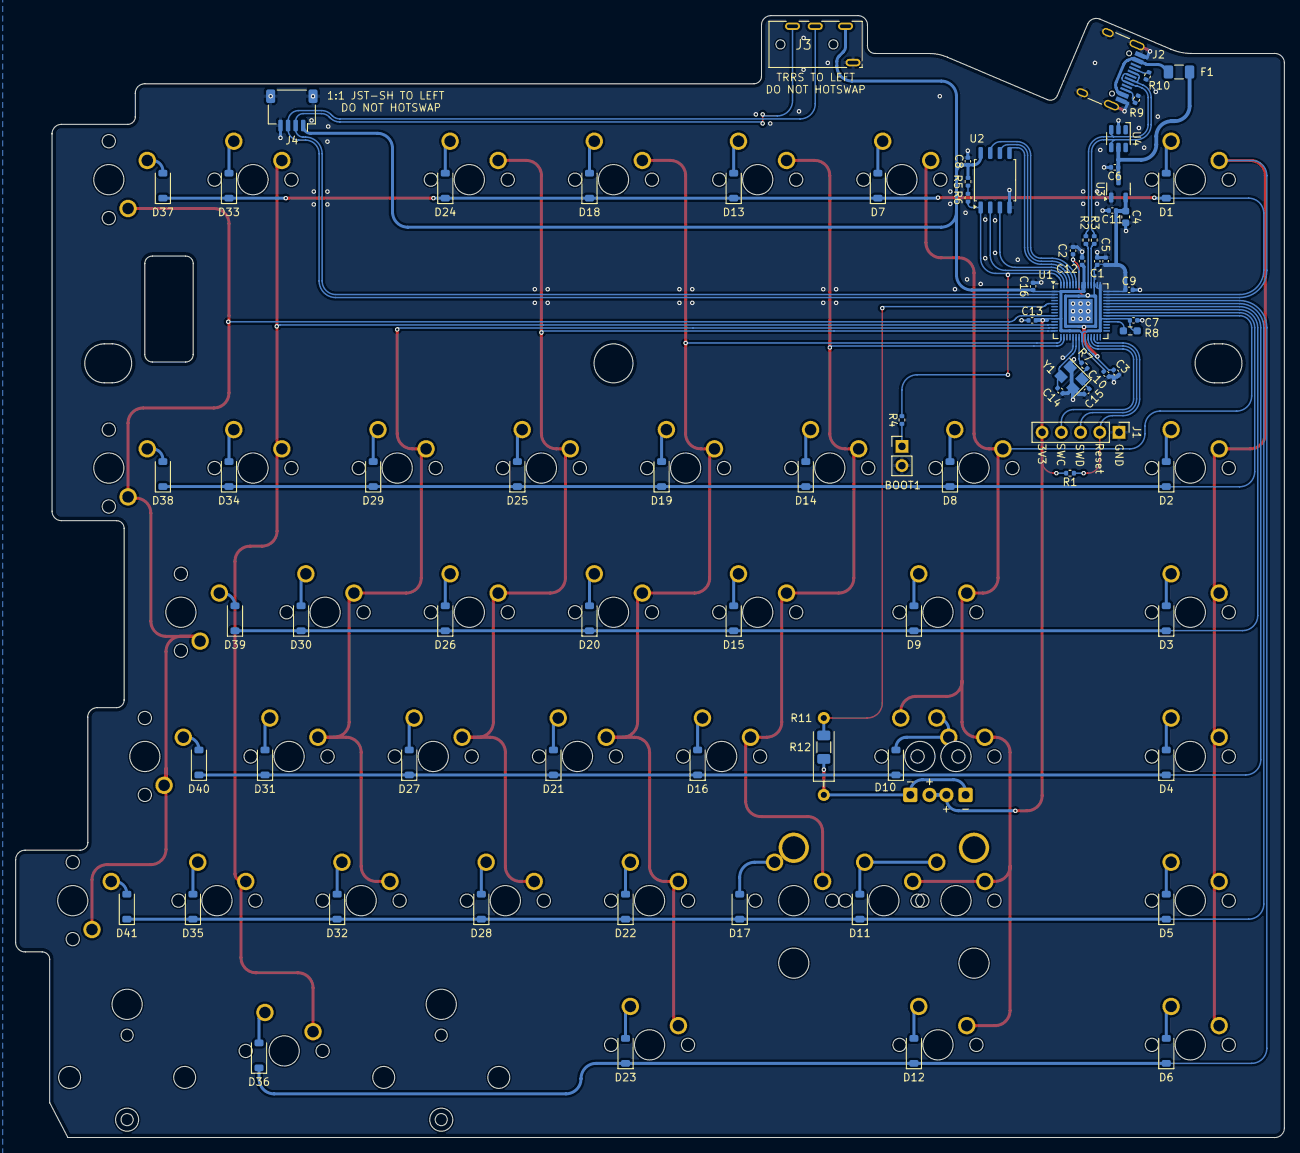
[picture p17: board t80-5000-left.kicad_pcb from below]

Board: 2 copper layers, 167.6 x 148.2 mm, 128 parts (80 on the bottom side), 85 nets.

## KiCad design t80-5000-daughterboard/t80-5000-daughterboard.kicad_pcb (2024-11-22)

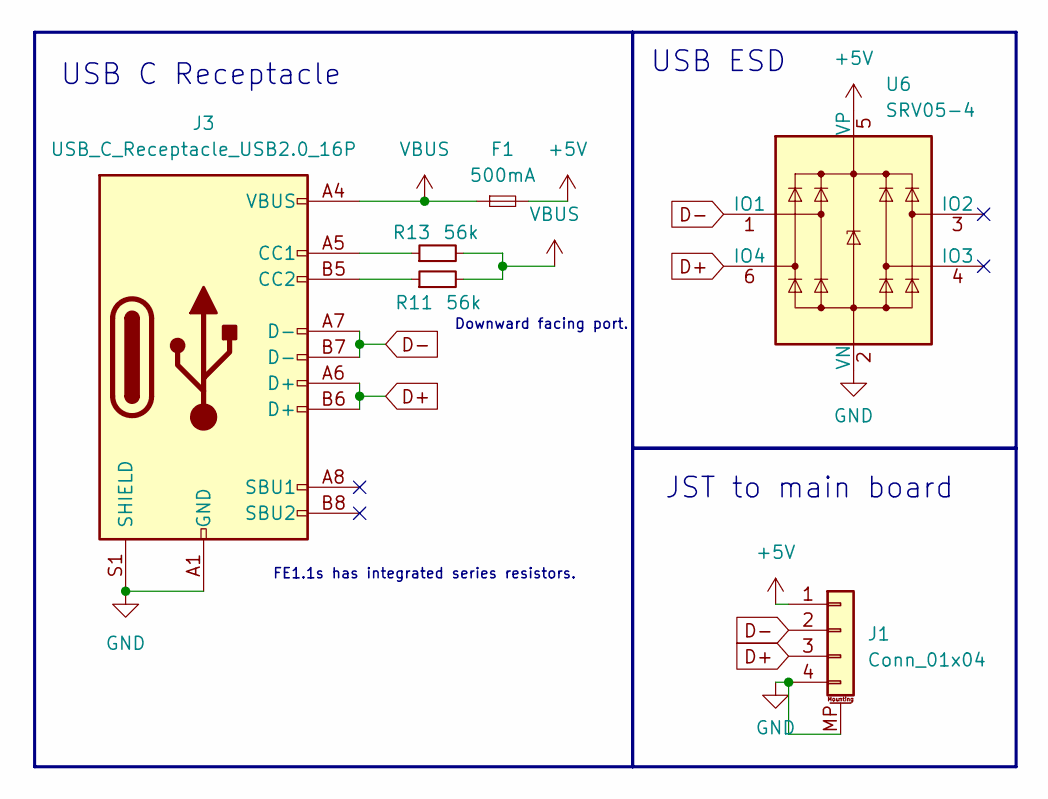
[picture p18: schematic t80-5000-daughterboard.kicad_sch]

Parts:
F1: 500mA; Fuse_1206_3216Metric
J1: Conn_01x04; JST_SH_SM04B-SRSS-TB_1x04-1MP_P1.00mm_Horizontal
J3: USB_C_Receptacle_USB2.0_16P; USB-C-SMD_HANBO_MC-121-L119
R11, R13: 56k; R_0402_1005Metric
U6: SRV05-4; SOT-23-6-routable

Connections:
+5V: F1.2, J1.1, U6.5 (VP)
D+: J1.3, J3.A6 (D+), J3.B6 (D+), U6.6 (IO4)
D-: J1.2, J3.A7 (D-), J3.B7 (D-), U6.1 (IO1)
GND: J1.4, J1.MP (MountPin), J3.A1 (GND), J3.A12 (GND), J3.B1 (GND), J3.B12 (GND), J3.S1 (SHIELD), U6.2 (VN)
unnamed: J3.A5 (CC1), R13.1
unnamed: J3.B5 (CC2), R11.1
VBUS: F1.1, J3.A4 (VBUS), J3.A9 (VBUS), J3.B4 (VBUS), J3.B9 (VBUS), R11.2, R13.2

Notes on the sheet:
FE1.1s has integrated series resistors.
Downward facing port.
JST to main board
USB C Receptacle
USB ESD

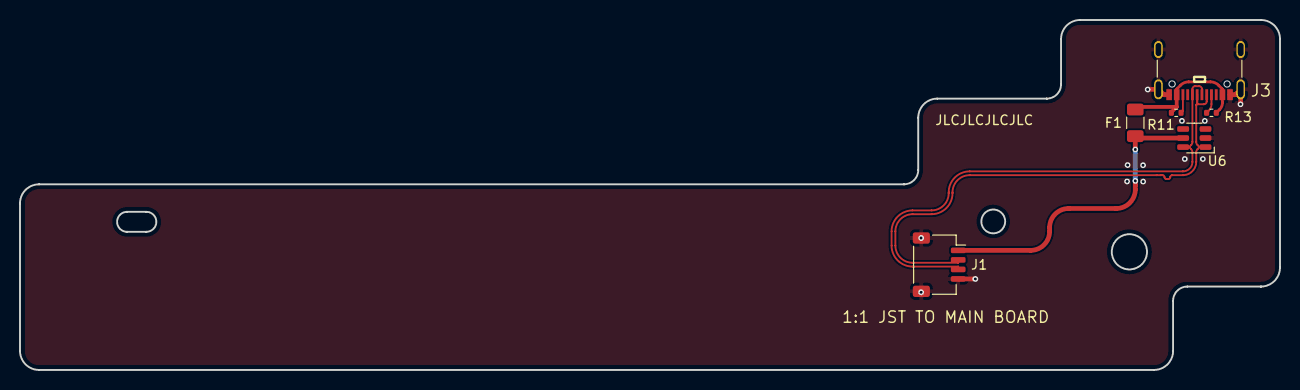
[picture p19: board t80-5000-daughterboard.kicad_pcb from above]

Board: 2 copper layers, 132.3 x 36.8 mm, 6 parts (0 on the bottom side), 7 nets.

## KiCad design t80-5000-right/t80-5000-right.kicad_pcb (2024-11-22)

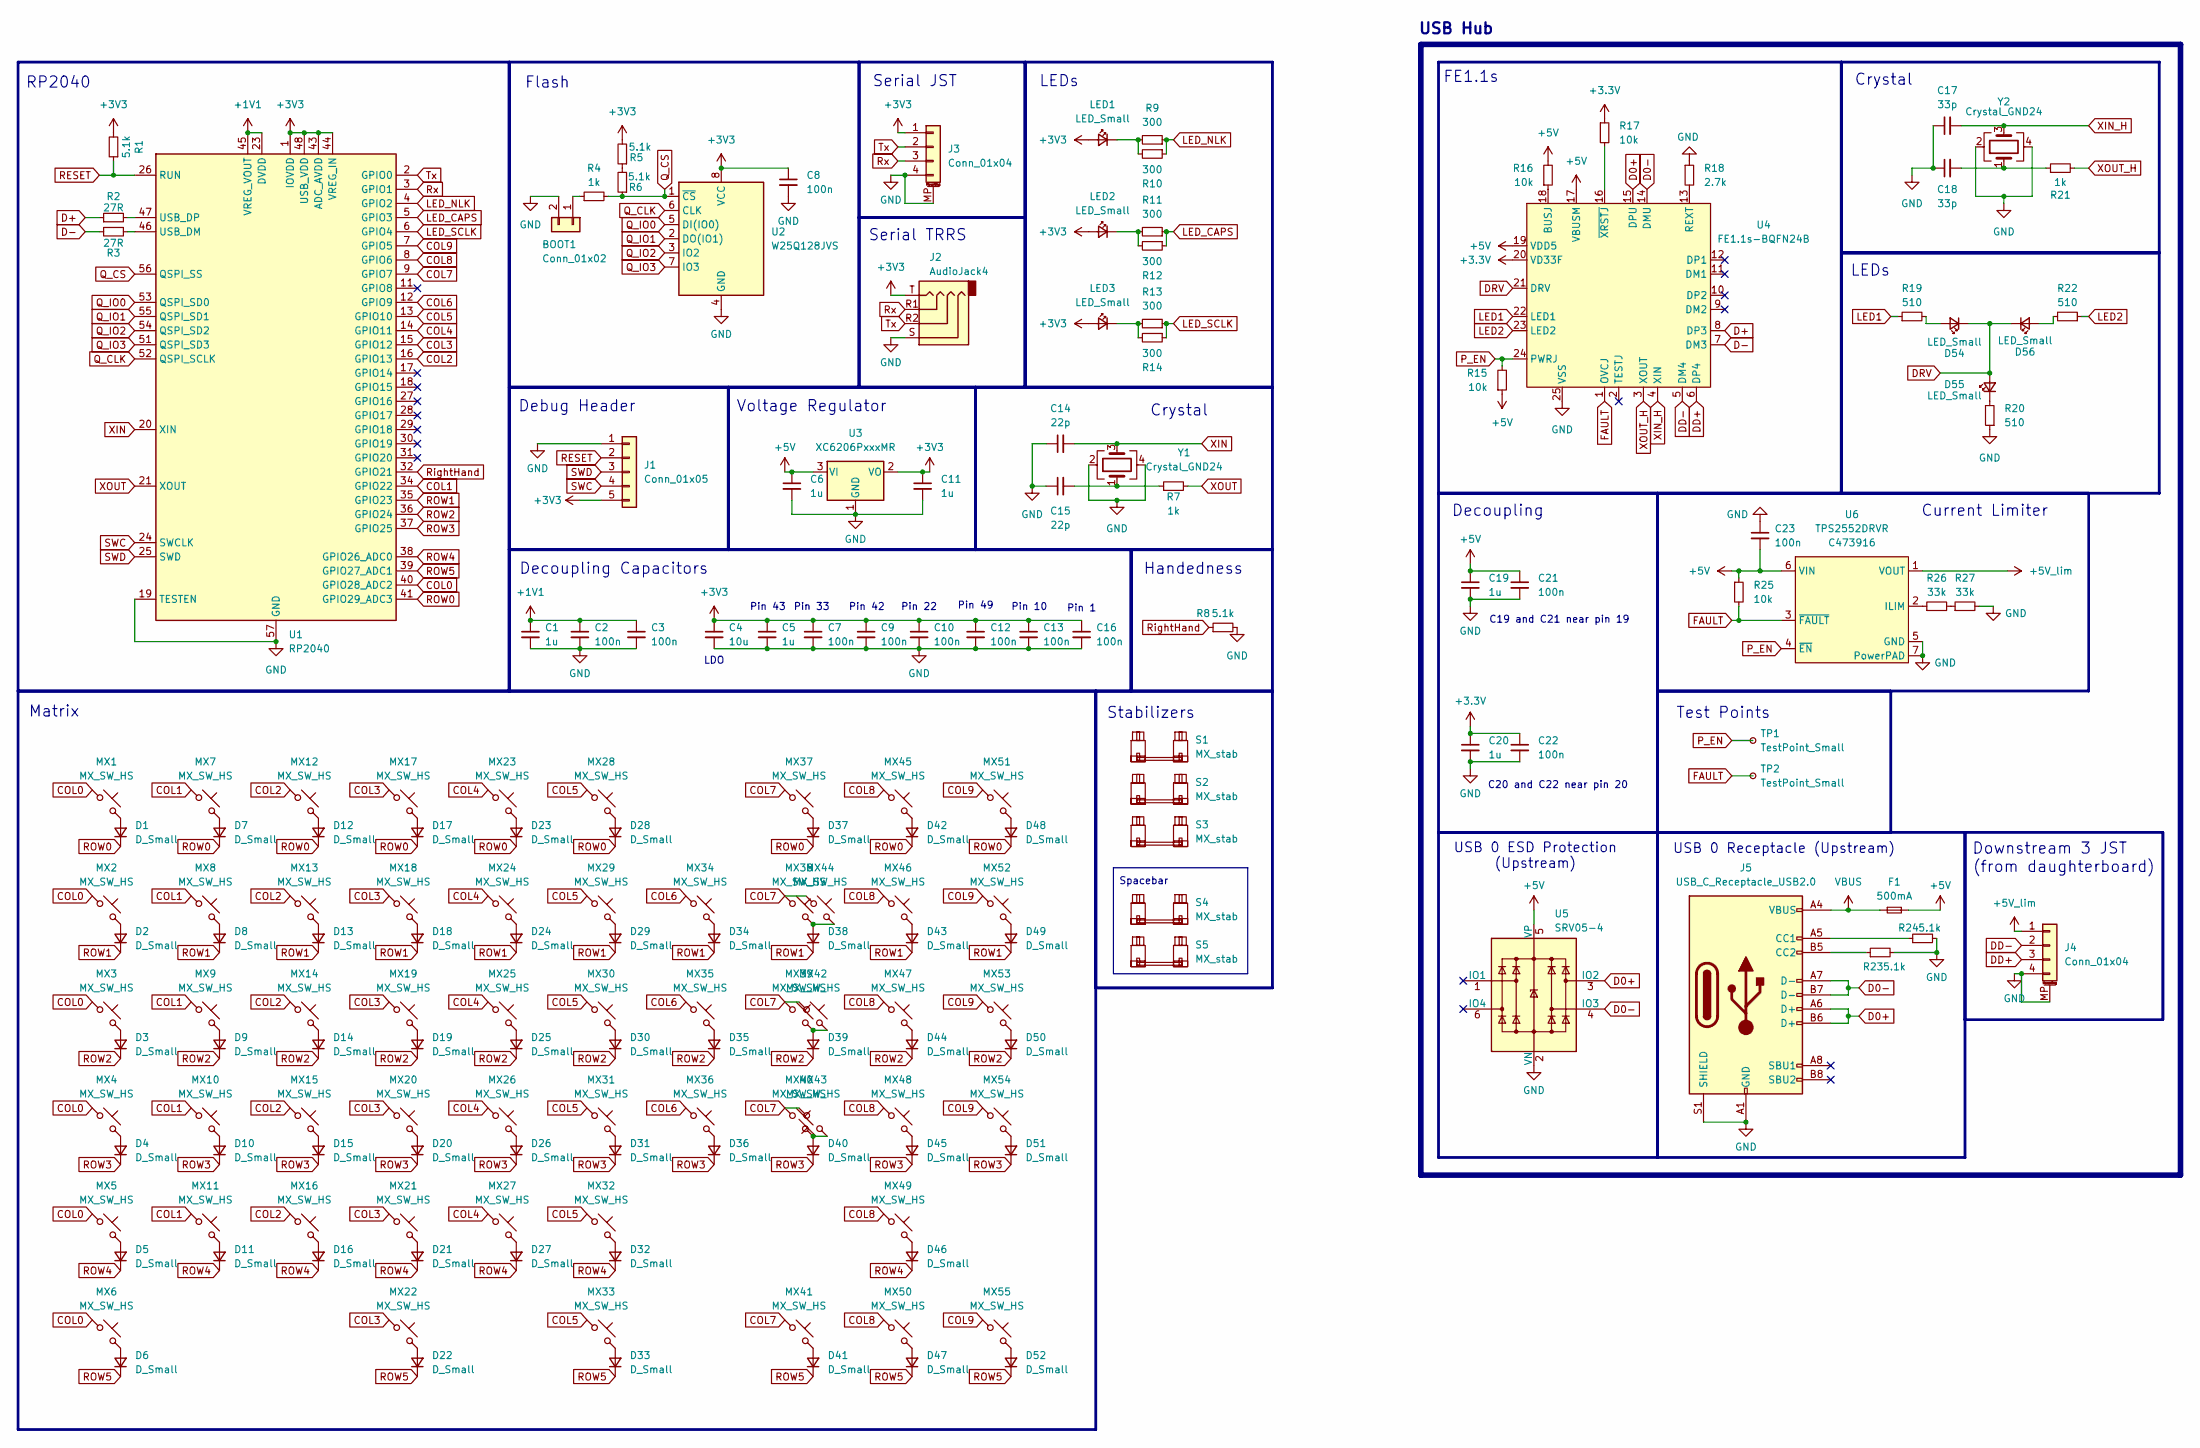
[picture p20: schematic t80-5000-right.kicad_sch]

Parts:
BOOT1: Conn_01x02; PinHeader_1x02_P2.54mm_Vertical
C1, C5, C6, C11, C19, C20: 1u; C_0402_1005Metric
C2, C3, C7, C8, C9, C10, C12, C13, C16, C21, C22, C23: 100n; C_0402_1005Metric
C4: 10u; C_0603_1608Metric
C14, C15: 22p; C_0402_1005Metric
C17, C18: 33p; C_0402_1005Metric
D1, D2, D3, D4, D5, D6, D7, D8, D9, D10, D11, D12, D13, D14, D15, D16, D17, D18, D19, D20, D21, D22, D23, D24, D25, D26, D27, D28, D29, D30, D31, D32, D33, D34, D35, D36, D37, D38, D39, D40, D41, D42, D43, D44, D45, D46, D47, D48, D49, D50, D51, D52: D_Small; D_SOD-123-ShiftedSoldermask
D54, D55, D56: LED_Small; LED_0603_1608Metric
F1: 500mA; Fuse_1206_3216Metric
J1: Conn_01x05; PinHeader_1x05_P2.54mm_Vertical
J2: AudioJack4; AUDIO-TH_XKB_PJ-320A
J3, J4: Conn_01x04; JST_SH_SM04B-SRSS-TB_1x04-1MP_P1.00mm_Horizontal
J5: USB_C_Receptacle_USB2.0; USB-C-SMD_GT-USB-7014D
LED1, LED2, LED3: LED_Small; LED_D5.0mm
MX1, MX2, MX3, MX4, MX5, MX6, MX7, MX8, MX9, MX10, MX11, MX12, MX13, MX14, MX15, MX16, MX17, MX18, MX19, MX20, MX21, MX22, MX23, MX24, MX25, MX26, MX27, MX28, MX29, MX30, MX31, MX32, MX33, MX34, MX35, MX36, MX37, MX38, MX39, MX40, MX41, MX42, MX43, MX44, MX45, MX46, MX47, MX48, MX49, MX50, MX51, MX52, MX53, MX54, MX55: MX_SW_HS; SW_MX_1u
R1, R5, R6, R23, R24: 5.1k; R_0402_1005Metric
R2, R3: 27R; R_0402_1005Metric
R4, R7, R21: 1k; R_0402_1005Metric
R8: 5.1k; R_0603_1608Metric_Pad0.98x0.95mm_HandSolder
R9, R11, R13: 300; R_Axial_DIN0207_L6.3mm_D2.5mm_P10.16mm_Horizontal
R10, R12, R14: 300; R_1206_3216Metric_Pad1.30x1.75mm_HandSolder
R15, R16, R17, R25: 10k; R_0402_1005Metric
R18: 2.7k; R_0603_1608Metric
R19, R20, R22: 510; R_0402_1005Metric
R26, R27: 33k; R_0402_1005Metric
S1, S2, S3: MX_stab; STAB_MX_P_2u
S4: MX_stab; STAB_MX_3.5u_5000
S5: MX_stab; STAB_MX_5000
TP1, TP2: TestPoint_Small; TestPoint_THTPad_D1.0mm_Drill0.5mm
U1: RP2040; QFN-56-1EP_7x7mm_P0.4mm_EP3.2x3.2mm
U2: W25Q128JVS; SOIC-8_5.23x5.23mm_P1.27mm
U3: XC6206PxxxMR; SOT-23-3
U4: FE1.1s-BQFN24B; WQFN-24-1EP_4x4mm_P0.5mm_EP2.6x2.6mm
U5: SRV05-4; SOT-23-6-routable
U6: TPS2552DRVR; WSON-6-1EP_2x2mm_P0.65mm_EP1x1.6mm_ThermalVias; LCSC C473916
Y1, Y2: Crystal_GND24; Crystal_SMD_3225-4Pin_3.2x2.5mm

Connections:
+1V1: C1.1, C2.1, C3.1, U1.23 (DVDD), U1.45 (VREG_VOUT), U1.50 (DVDD)
+3.3V: C20.1, C22.1, R17.1, U4.20 (VD33F)
+3V3: C4.1, C5.1, C7.1, C8.1, C9.1, C10.1, C11.1, C12.1, C13.1, C16.1, J1.5, J2.T, J3.1, LED1.2 (A), LED2.2 (A), LED3.2 (A), R1.2, R5.2, U1.1 (IOVDD), U1.10 (IOVDD), U1.22 (IOVDD), U1.33 (IOVDD), U1.42 (IOVDD), U1.43 (ADC_AVDD), U1.44 (VREG_IN), U1.48 (USB_VDD), U1.49 (IOVDD), U2.8 (VCC), U3.2 (VO)
+5V: C6.1, C19.1, C21.1, C23.2, F1.2, R15.1, R16.2, R25.1, U3.3 (VI), U4.17 (VBUSM), U4.19 (VDD5), U5.5 (VP), U6.6 (VIN)
+5V_lim: J4.1, U6.1 (VOUT)
COL0: MX1.1, MX2.1, MX3.1, MX4.1, MX5.1, MX6.1, U1.40 (GPIO28_ADC2)
COL1: MX7.1, MX8.1, MX9.1, MX10.1, MX11.1, U1.34 (GPIO22)
COL2: MX12.1, MX13.1, MX14.1, MX15.1, MX16.1, U1.16 (GPIO13)
COL3: MX17.1, MX18.1, MX19.1, MX20.1, MX21.1, MX22.1, U1.15 (GPIO12)
COL4: MX23.1, MX24.1, MX25.1, MX26.1, MX27.1, U1.14 (GPIO11)
COL5: MX28.1, MX29.1, MX30.1, MX31.1, MX32.1, MX33.1, U1.13 (GPIO10)
COL6: MX34.1, MX35.1, MX36.1, U1.12 (GPIO9)
COL7: MX37.1, MX38.1, MX39.1, MX40.1, MX41.1, MX42.1, MX43.2, MX44.1, U1.9 (GPIO7)
COL8: MX45.1, MX46.1, MX47.1, MX48.1, MX49.1, MX50.1, U1.8 (GPIO6)
COL9: MX51.1, MX52.1, MX53.1, MX54.1, MX55.1, U1.7 (GPIO5)
D0+: J5.A6 (D+), J5.B6 (D+), U4.15 (DPU), U5.3 (IO2)
D0-: J5.A7 (D-), J5.B7 (D-), U4.14 (DMU), U5.4 (IO3)
D+: R2.1, U4.8 (DP3)
D-: R3.2, U4.7 (DM3)
DD+: J4.3, U4.6 (DP4)
DD-: J4.2, U4.5 (DM4)
DRV: D54.1 (K), D55.2 (A), D56.1 (K), U4.21 (DRV)
FAULT: R25.2, TP2.1, U4.1 (OVCJ), U6.3 (~FAULT)
GND: BOOT1.2, C1.2, C2.2, C3.2, C4.2, C5.2, C6.2, C7.2, C8.2, C9.2, C10.2, C11.2, C12.2, C13.2, C14.1, C15.1, C16.2, C17.1, C18.1, C19.2, C20.2, C21.2, C22.2, C23.1, J1.1, J2.S, J3.4, J3.MP (MountPin), J4.4, J4.MP (MountPin), J5.A1 (GND), J5.A12 (GND), J5.B1 (GND), J5.B12 (GND), J5.S1 (SHIELD), R8.2, R18.1, R20.1, R23.2, R24.2, R27.2, U1.19 (TESTEN), U1.57 (GND), U2.4 (GND), U3.1 (GND), U4.25 (VSS), U5.2 (VN), U6.5 (GND), U6.7 (PowerPAD), Y1.2, Y1.4, Y2.2, Y2.4
LED1: R19.1, U4.22 (LED1)
LED2: R22.1, U4.23 (LED2)
LED_CAPS: R11.1, R12.1, U1.5 (GPIO3)
LED_NLK: R9.1, R10.1, U1.4 (GPIO2)
LED_SCLK: R13.1, R14.1, U1.6 (GPIO4)
unnamed: BOOT1.1, R4.1
unnamed: C15.2, R7.1, Y1.1
unnamed: C18.2, R21.1, Y2.1
unnamed: D1.2 (A), MX1.2
unnamed: D2.2 (A), MX2.2
unnamed: D3.2 (A), MX3.2
unnamed: D4.2 (A), MX4.2
unnamed: D5.2 (A), MX5.2
unnamed: D6.2 (A), MX6.2
unnamed: D7.2 (A), MX7.2
unnamed: D8.2 (A), MX8.2
unnamed: D9.2 (A), MX9.2
unnamed: D10.2 (A), MX10.2
unnamed: D11.2 (A), MX11.2
unnamed: D12.2 (A), MX12.2
unnamed: D13.2 (A), MX13.2
unnamed: D14.2 (A), MX14.2
unnamed: D15.2 (A), MX15.2
unnamed: D16.2 (A), MX16.2
unnamed: D17.2 (A), MX17.2
unnamed: D18.2 (A), MX18.2
unnamed: D19.2 (A), MX19.2
unnamed: D20.2 (A), MX20.2
unnamed: D21.2 (A), MX21.2
unnamed: D22.2 (A), MX22.2
unnamed: D23.2 (A), MX23.2
unnamed: D24.2 (A), MX24.2
unnamed: D25.2 (A), MX25.2
unnamed: D26.2 (A), MX26.2
unnamed: D27.2 (A), MX27.2
unnamed: D28.2 (A), MX28.2
unnamed: D29.2 (A), MX29.2
unnamed: D30.2 (A), MX30.2
unnamed: D31.2 (A), MX31.2
unnamed: D32.2 (A), MX32.2
unnamed: D33.2 (A), MX33.2
unnamed: D34.2 (A), MX34.2
unnamed: D35.2 (A), MX35.2
unnamed: D36.2 (A), MX36.2
unnamed: D37.2 (A), MX37.2
unnamed: D38.2 (A), MX38.2, MX44.2
unnamed: D39.2 (A), MX39.2, MX42.2
unnamed: D40.2 (A), MX40.2, MX43.1
unnamed: D41.2 (A), MX41.2
unnamed: D42.2 (A), MX45.2
unnamed: D43.2 (A), MX46.2
unnamed: D44.2 (A), MX47.2
unnamed: D45.2 (A), MX48.2
unnamed: D46.2 (A), MX49.2
unnamed: D47.2 (A), MX50.2
unnamed: D48.2 (A), MX51.2
unnamed: D49.2 (A), MX52.2
unnamed: D50.2 (A), MX53.2
unnamed: D51.2 (A), MX54.2
unnamed: D52.2 (A), MX55.2
unnamed: D54.2 (A), R19.2
unnamed: D55.1 (K), R20.2
unnamed: D56.2 (A), R22.2
unnamed: J5.A5 (CC1), R24.1
unnamed: J5.B5 (CC2), R23.1
unnamed: LED1.1 (K), R9.2, R10.2
unnamed: LED2.1 (K), R11.2, R12.2
unnamed: LED3.1 (K), R13.2, R14.2
unnamed: R5.1, R6.2
unnamed: R26.2, R27.1
unnamed: R3.1, U1.46 (USB_DM)
unnamed: R2.2, U1.47 (USB_DP)
unnamed: R16.1, U4.18 (BUSJ)
unnamed: R18.2, U4.13 (REXT)
unnamed: R17.2, U4.16 (~XRSTJ)
unnamed: R26.1, U6.2 (ILIM)
P_EN: R15.2, TP1.1, U4.24 (PWRJ), U6.4 (~EN)
Q_CLK: U1.52 (QSPI_SCLK), U2.6 (CLK)
Q_CS: R4.2, R6.1, U1.56 (QSPI_SS), U2.1 (~CS)
Q_IO0: U1.53 (QSPI_SD0), U2.5 (DI(IO0))
Q_IO1: U1.55 (QSPI_SD1), U2.2 (DO(IO1))
Q_IO2: U1.54 (QSPI_SD2), U2.3 (IO2)
Q_IO3: U1.51 (QSPI_SD3), U2.7 (IO3)
RESET: J1.2, R1.1, U1.26 (RUN)
ROW0: D1.1 (K), D7.1 (K), D12.1 (K), D17.1 (K), D23.1 (K), D28.1 (K), D37.1 (K), D42.1 (K), D48.1 (K), U1.41 (GPIO29_ADC3)
ROW1: D2.1 (K), D8.1 (K), D13.1 (K), D18.1 (K), D24.1 (K), D29.1 (K), D34.1 (K), D38.1 (K), D43.1 (K), D49.1 (K), U1.35 (GPIO23)
ROW2: D3.1 (K), D9.1 (K), D14.1 (K), D19.1 (K), D25.1 (K), D30.1 (K), D35.1 (K), D39.1 (K), D44.1 (K), D50.1 (K), U1.36 (GPIO24)
ROW3: D4.1 (K), D10.1 (K), D15.1 (K), D20.1 (K), D26.1 (K), D31.1 (K), D36.1 (K), D40.1 (K), D45.1 (K), D51.1 (K), U1.37 (GPIO25)
ROW4: D5.1 (K), D11.1 (K), D16.1 (K), D21.1 (K), D27.1 (K), D32.1 (K), D46.1 (K), U1.38 (GPIO26_ADC0)
ROW5: D6.1 (K), D22.1 (K), D33.1 (K), D41.1 (K), D47.1 (K), D52.1 (K), U1.39 (GPIO27_ADC1)
RightHand: R8.1, U1.32 (GPIO21)
Rx: J2.R1, J3.3, U1.3 (GPIO1)
SWC: J1.4, U1.24 (SWCLK)
SWD: J1.3, U1.25 (SWD)
Tx: J2.R2, J3.2, U1.2 (GPIO0)
VBUS: F1.1, J5.A4 (VBUS), J5.A9 (VBUS), J5.B4 (VBUS), J5.B9 (VBUS)
XIN: C14.2, U1.20 (XIN), Y1.3
XIN_H: C17.2, U4.4 (XIN), Y2.3
XOUT: R7.2, U1.21 (XOUT)
XOUT_H: R21.2, U4.3 (XOUT)

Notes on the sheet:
Decoupling
Serial TRRS
Pin 10
LDO
Spacebar
Decoupling Capacitors
Serial JST
Crystal
FE1.1s
LEDs
Pin 43
Downstream 3 JST
Pin 42
USB Hub
Stabilizers
USB 0 Receptacle (Upstream)
(from daughterboard)
Debug Header
C19 and C21 near pin 19
Pin 22
C20 and C22 near pin 20
Test Points
Current Limiter
Pin 33
USB 0 ESD Protection (Upstream)
Pin 49
RP2040
Matrix
Handedness
Flash
Pin 1
Voltage Regulator

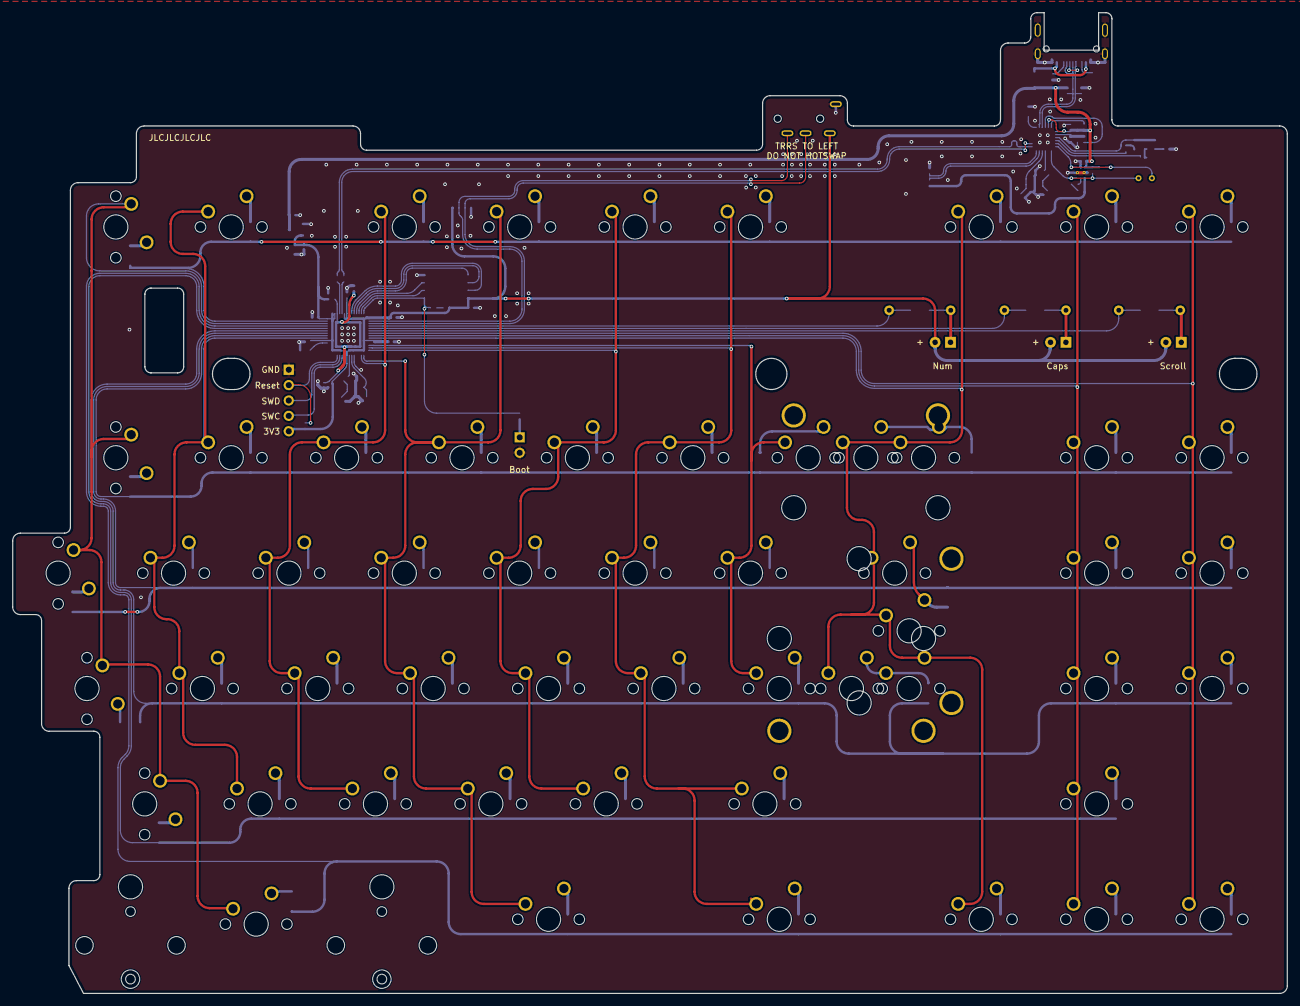
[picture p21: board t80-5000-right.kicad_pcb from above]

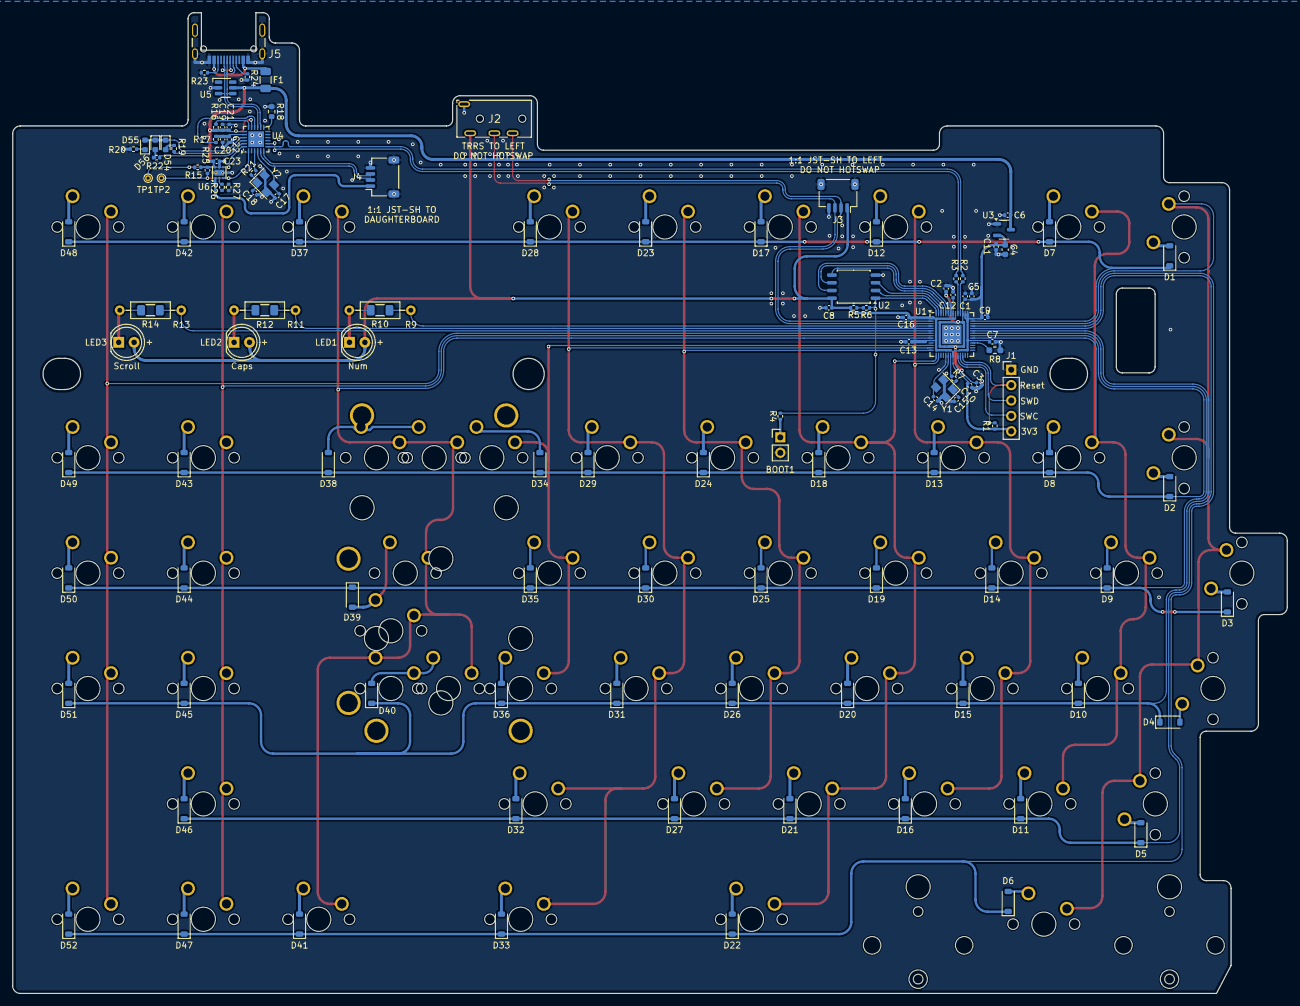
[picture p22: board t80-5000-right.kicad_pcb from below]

Board: 2 copper layers, 210.4 x 161.9 mm, 185 parts (125 on the bottom side), 124 nets.
